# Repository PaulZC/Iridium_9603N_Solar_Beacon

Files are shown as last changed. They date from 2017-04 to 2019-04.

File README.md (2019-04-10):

# Iridium 9603N Solar Beacon

A 48g solar powered Iridium 9603N + GNSS Beacon (Tracker)

Suitable for high altitude ballooning, asset tracking and many other remote monitoring applications.

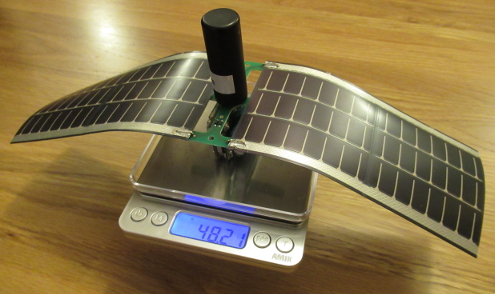
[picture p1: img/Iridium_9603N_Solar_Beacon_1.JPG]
Iridium_9603N_Solar_Beacon_1


The beacon can be powered by two [PowerFilm Solar MPT3.6-150 solar panels](https://www.powerfilmsolar.com/custom-solutions/electronic-component-solar-panels/electronic-component-solar-panels-product-page/mpt3-6-150).
It can also be powered via USB becoming an extremely small Iridium Beacon Base which you can use to track other beacons from anywhere.

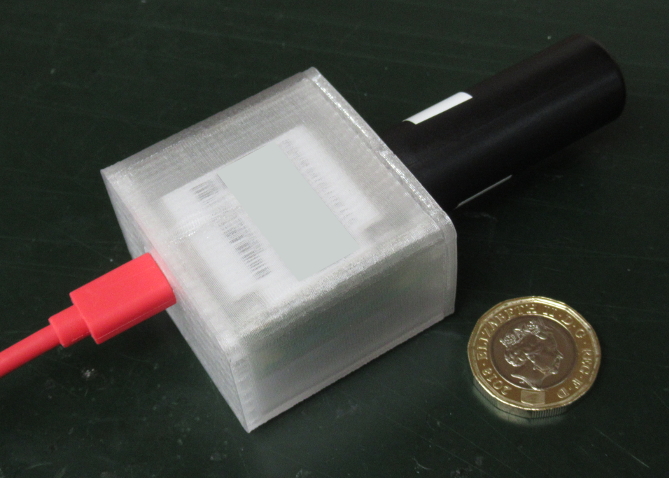
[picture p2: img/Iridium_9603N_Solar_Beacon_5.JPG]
Iridium_9603N_Solar_Beacon_5


The Iridium 9603N and u-blox MAX-M8Q GNSS share a single antenna. Antenna switching is performed by a Skyworks AS179-92LF RF Switch.

**See [LEARN.md](https://github.com/PaulZC/Iridium_9603N_Solar_Beacon/blob/master/LEARN.md) for more details.**

**See [ASSEMBLY.md](https://github.com/PaulZC/Iridium_9603N_Solar_Beacon/blob/master/ASSEMBLY.md) for details on how to assemble the PCB.**

See [Iridium_9603N_Solar_Beacon.pdf](https://github.com/PaulZC/Iridium_9603N_Solar_Beacon/blob/master/Iridium_9603N_Solar_Beacon.pdf) for the schematic, layout and Bill Of Materials.

The [Eagle](https://github.com/PaulZC/Iridium_9603N_Solar_Beacon/tree/master/Eagle) directory contains the schematic and pcb design files.

The [Arduino](https://github.com/PaulZC/Iridium_9603N_Solar_Beacon/tree/master/Arduino) directory contains the Arduino code.

The [OpenSCAD](https://github.com/PaulZC/Iridium_9603N_Solar_Beacon/tree/master/OpenSCAD) directory contains the .stl and .scad files for the 3D-printed cover and antenna spacer.

Please refer to the [Iridium_9603_Beacon Repo](https://github.com/PaulZC/Iridium_9603_Beacon/blob/master/RockBLOCK.md) for details on how to track your beacon
via the RockBLOCK Gateway with or without an Internet connection. If you are configuring the Solar Beacon as a Base, please make sure you use the version of
the Base code included in this Repo as the solar beacon pin definitions are slightly different and the code needs to ensure the 9603N and MAX-M8Q are not
powered up simultaneously when sharing the antenna.

If you have found this project useful and if you are able to, please cite the paper:

P. Clark et al, An open source toolkit for the tracking, termination and recovery of high altitude balloon flights and payloads, 2019 JINST 14 P04003
[DOI:10.1088/1748-0221/14/04/P04003](https://doi.org/10.1088/1748-0221/14/04/P04003)

The Accepted Manuscript is available on arXiv: http://arxiv.org/abs/1904.04321

This project is distributed under a Creative Commons Attribution + Share-alike (BY-SA) licence.
Please refer to section 5 of the licence for the "Disclaimer of Warranties and Limitation of Liability".

Enjoy!

**_Paul_**

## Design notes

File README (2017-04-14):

########################################
# Iridium 9603N Solar Beacon Prototype #
########################################

A breadboard prototype for a Solar Powered Iridium 9603N Beacon.

Power for the beacon is provided by a PowerFilm MPT3.6-150 solar panel.

Power for the Iridium 9603N is provided by a Linear Technology LTC3225EDDB supercapacitor charger.

See Iridium_9603N_Solar_Beacon_Prototype.pdf for a full description of the project:
https://github.com/PaulZC/Iridium_9603N_Solar_Beacon/blob/master/Iridium_9603N_Solar_Beacon_Prototype.pdf

The Arduino code can be found in Iridium9603NSolarBeaconPrototype
https://github.com/PaulZC/Iridium_9603N_Solar_Beacon/tree/master/Iridium9603NSolarBeaconPrototype

A Fritzing hook-up diagram can be found in Iridium_9603N_Solar_Beacon_Prototype_Fritzing.png
https://github.com/PaulZC/Iridium_9603N_Solar_Beacon/blob/master/Iridium_9603N_Solar_Beacon_Prototype_Fritzing.png

This project is distributed under a Creative Commons Attribution + Share-alike (BY-SA) licence.

Enjoy!

Paul

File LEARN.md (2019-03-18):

# Iridium 9603N Solar Beacon

A 48g solar powered Iridium 9603N + GNSS Beacon (Tracker)

Suitable for high altitude ballooning, asset tracking and many other remote monitoring applications.

Iridium_9603N_Solar_Beacon_1

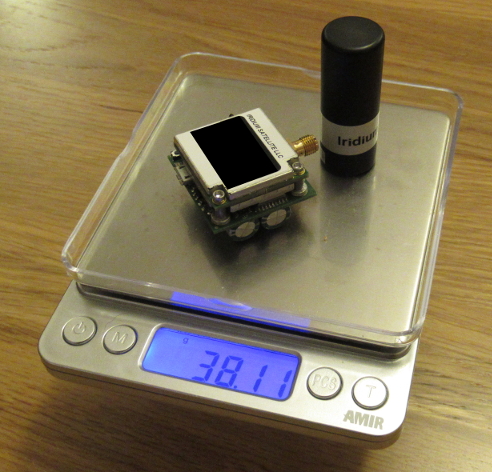
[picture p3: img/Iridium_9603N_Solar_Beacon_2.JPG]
Iridium_9603N_Solar_Beacon_2


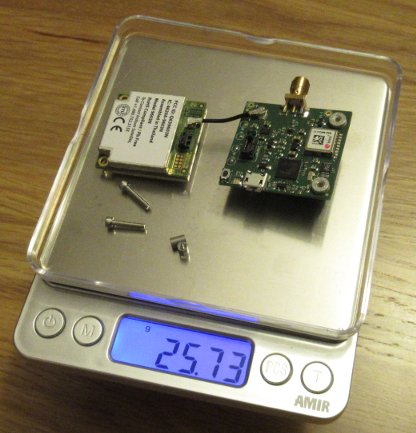
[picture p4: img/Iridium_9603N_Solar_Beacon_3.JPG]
Iridium_9603N_Solar_Beacon_3


## Background

The Iridium 9603N Solar Beacon is a miniature version of the [Iridium_9603_Beacon](https://github.com/PaulZC/Iridium_9603_Beacon).
It can be powered by two [PowerFilm Solar MPT3.6-150 solar panels](https://www.powerfilmsolar.com/custom-solutions/electronic-component-solar-panels/electronic-component-solar-panels-product-page/mpt3-6-150)
but can also be powered via USB becoming an extremely small Iridium Beacon Base which you can use to track other beacons without an Internet connection.

Iridium_9603N_Solar_Beacon_5

## The Design

See [Iridium_9603N_Solar_Beacon.pdf](https://github.com/PaulZC/Iridium_9603N_Solar_Beacon/blob/master/Iridium_9603N_Solar_Beacon.pdf) for the schematic,
layout and Bill Of Materials.

The [Eagle](https://github.com/PaulZC/Iridium_9603N_Solar_Beacon/tree/master/Eagle) directory contains the schematic and pcb design files.

The key components of the Iridium 9603N Solar Beacon are:

### Iridium 9603N Module
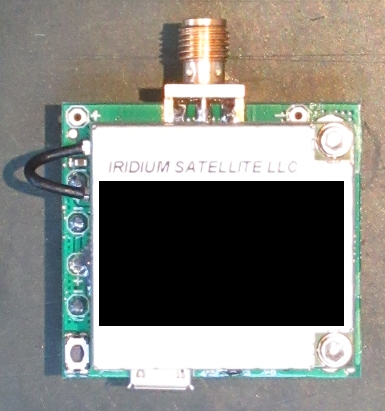
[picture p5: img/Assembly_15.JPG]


Available from:
- https://www.rock7.com/shop-product-detail?productId=50

Other UK and International distributors can be found at:
- https://www.iridium.com/where-to-buy/?pid=27083

Make sure you purchase the 9603N and not the older 9603. The 9603N will run from 5V ± 0.5V which is important as the super capacitor charger is set to produce 5.3V; the older 9603 is only rated to 5V ± 0.2V.

### SMA Iridium + GNSS Antenna
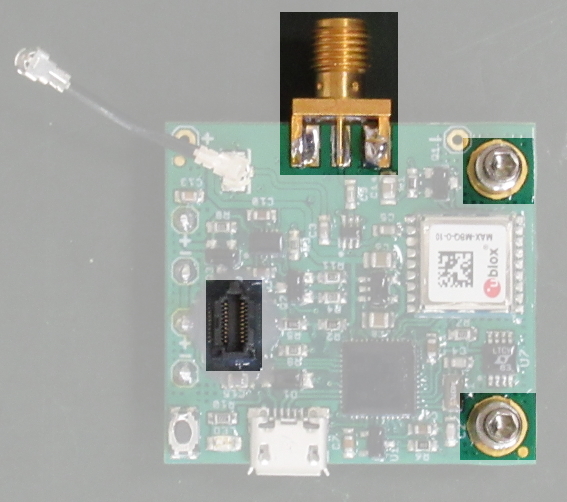
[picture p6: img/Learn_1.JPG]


For this version of the beacon, I recommend using the Maxtena M1600HCT-P-SMA which is tuned for the Iridium, GPS and GLONASS frequency bands.

### Atmel ATSAMD21G18 Processor
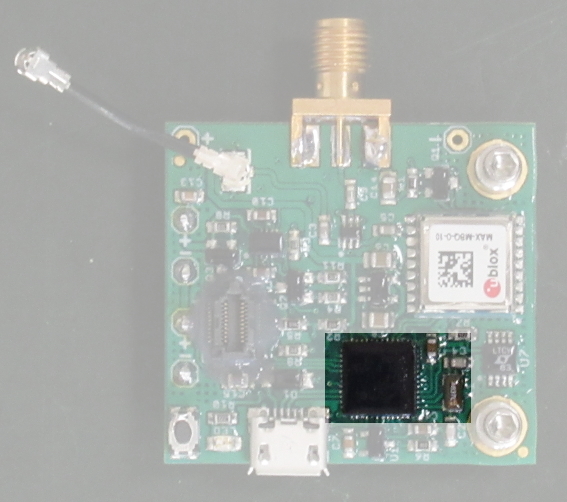
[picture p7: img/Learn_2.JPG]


As used on the Adafruit Feather M0:
- https://www.adafruit.com/products/2772

Available from e.g. Farnell / Element14 (2460544)

### Linear Technology LTC3225EDDB SuperCapacitor Charger
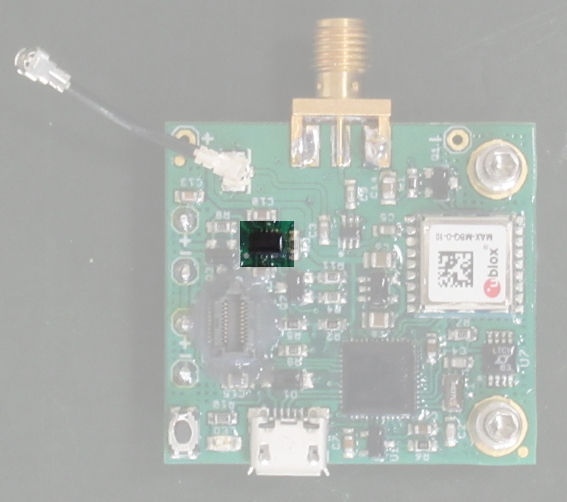
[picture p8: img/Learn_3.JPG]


- https://www.analog.com/en/products/ltc3225.html

Available as a bare chip from e.g. Farnell / Element14 (1715231)

### u-blox MAX-M8Q GNSS
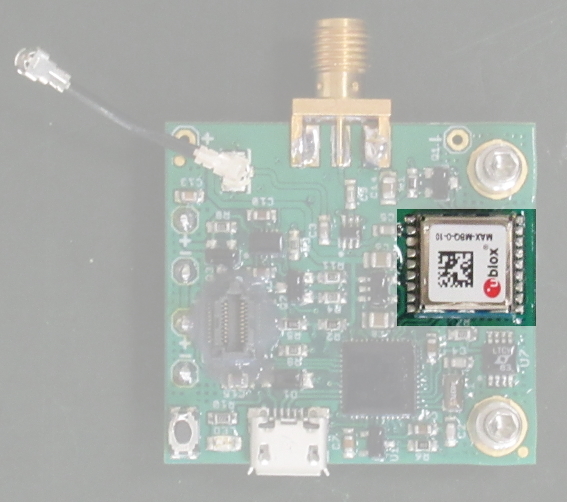
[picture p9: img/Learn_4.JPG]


- https://www.u-blox.com/en/product/max-m8-series

### MCP111T-240 Reset Supervisor
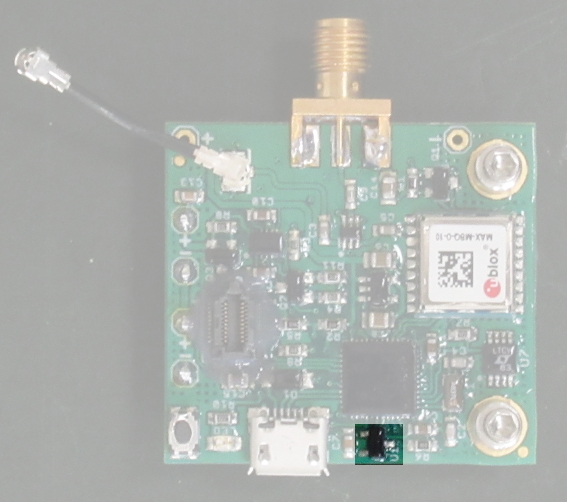
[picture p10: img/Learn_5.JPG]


The SAMD21G18 has a built-in power-on reset and brown-out detector circuit, but it doesn't work properly if the supply voltage rises very slowly.
The SAMD21G18 datasheet isn’t much help here. Section 8.2.4.1 specifies:
- _Minimum Rise Rate_

   _The integrated power-on reset (POR) circuitry monitoring the VDDANA power supply requires a minimum rise rate._

But then the supply characteristics section (37.4) specifies a _maximum_ supply rise rate of 0.1V/µs, not a minimum.

Tests I've carried out show that the processor will reset correctly if the power supply ramps up at 0.3 V/s or more, but fails to reset correctly at 0.2 V/s or less.
As the solar panel voltage will ramp up very slowly at sunrise, I've included a separate reset supervisor.
The Microchip MCP111-240 has an open drain output which holds the processor in reset until the supply rises above 2.4V, ensuring a clean start.

### SPX3819-3.3 Voltage Regulator
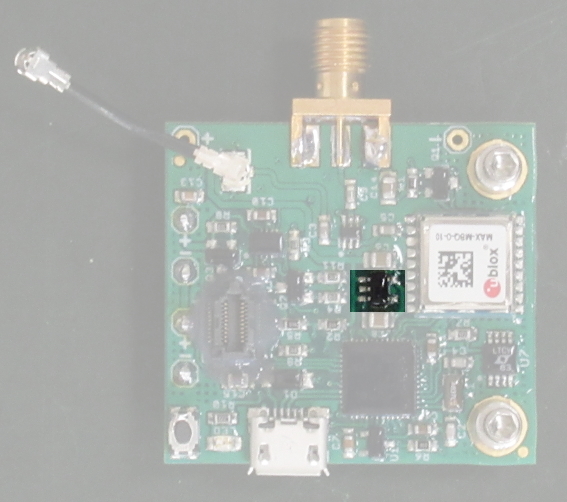
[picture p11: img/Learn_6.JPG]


The SPX3819-3.3 Voltage Regulator regulates the output from the two solar panels, or the USB port, providing 3.3V for the processor and GNSS.

The LTC3225EDDB SuperCapacitor Charger draws its power directly from the solar panels or USB without going through the regulator.

MBR120 diodes protect the solar panels and the USB port from each other.

### LT1634BCMS8-1.25 1.25V Voltage Reference
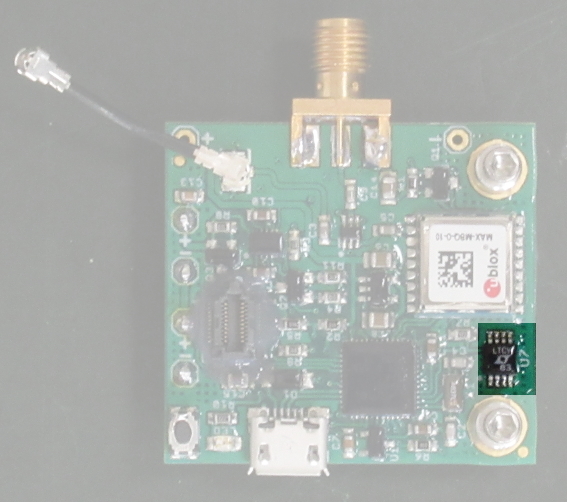
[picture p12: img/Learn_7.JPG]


The SAMD21G18 processor is powered from a low drop-out 3.3V regulator. The solar / USB voltage is measured via an analog pin connected to the mid point
of two 100K resistors configured as a voltage divider. The voltage measured by the analog pin is relative to the regulator voltage. When the power voltage drops below approximately
3.7V, the regulator voltage starts to collapse. The analog voltage appears to never drop below approximately 3.4V even when the actual voltage is lower than this.

By adding a 1.25V voltage reference and connecting it to a second analog pin, its constant voltage will appear to increase as the regulator voltage starts to collapse.
This voltage increase can be used to correct the power voltage measurement.

### Skyworks AS179-92LF RF Switch

The Iridium 9603N and MAX-M8Q GNSS receiver share the same antenna. A Skyworks AS179-92LF RF switch is used to switch the antenna connection from one to the other according to which is powered up.
Most importantly, the RF switch disconnects and protects the GNSS receiver when the Iridium 9603N is transmitting.

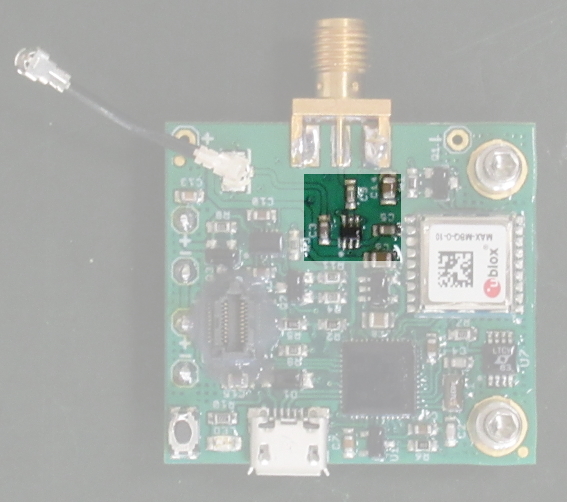
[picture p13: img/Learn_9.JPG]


Switching is performed by applying either EXT_PWR or 3V3SW to the AS179's V1 and V2 pins.
EXT_PWR is the 5.3V power rail for the 9603N (switched via Q2 and Q3, enabled by pulling MISO/D22 high).
3V3SW is the 3.3V power rail for the MAX-M8Q (switched via Q1, enabled by pulling D11 low).
When modifying the Arduino code, take great care to make sure EXT_PWR and 3V3SW are not enabled at the same time.
**BADS THINGS WILL PROBABLY HAPPEN IF YOU DO ENABLE BOTH SIMULTANEOUSLY!**

### Two PowerFilm Solar MPT3.6-150 solar panels


- https://www.powerfilmsolar.com/custom-solutions/electronic-component-solar-panels/electronic-component-solar-panels-product-page/mpt3-6-150

Available (in the UK) from e.g.:
- http://www.selectsolar.co.uk/prod/264/powerfilm-mpt36150-100ma-36v-mini-solar-panel

### Iridum 9603N Power Switching

The datasheet for the 9603N contains a note which says:

_When a transceiver has been turned off, Product Developers should not reapply power on a unit until more than 2 seconds has elapsed after power has reached 0V. Additionally, if a unit does not respond to AT commands, power off the module, wait for 2 seconds and then power it back on._

_When a 9603 is powered off the power on reset circuit requires 2 seconds for voltages to decay. If the 2 second wait time is not adhered to the reset circuit may not operate and the modem could be placed in a non-operational state. The state is not permanent and can be rectified by the above procedure._

I have seen a 9603N go into this non-operational state only twice. Unfortunately, with the previous versions of the beacon design,
the only way to completely remove power to the 9603N was to manually discharge the super capacitors. Obviously it would be disastrous if this happened
during a flight. So, a P-MOSFET (Q3) is used as a switch to disconnect the power to the 9603N when required.

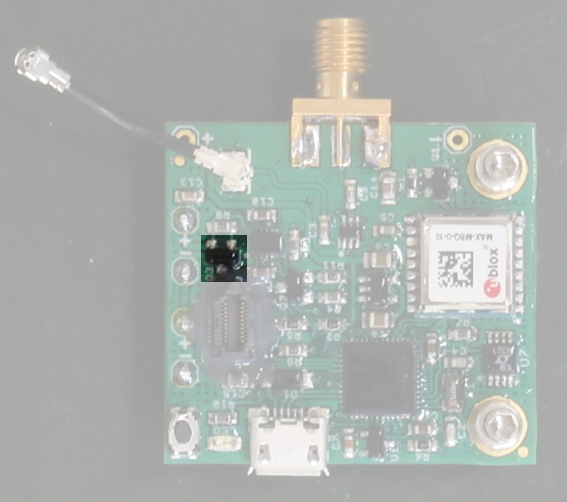
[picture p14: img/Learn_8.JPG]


### IO Pins
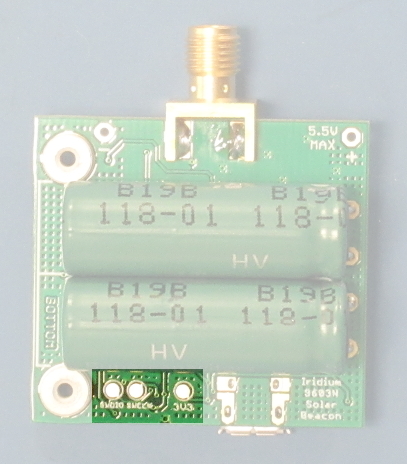
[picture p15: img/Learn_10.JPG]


**SWCLK** and **SWDIO** are used during [programming of the SAMD bootloader](https://github.com/PaulZC/Iridium_9603N_Solar_Beacon/blob/master/LEARN.md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)

**3V3** is the 3.3V power rail from the SPX3819-3.3 voltage regulator.

## Why does the beacon LED flash?
The small red LED indicates what the beacon software is doing. The LED:

- will flash at 0.5Hz (1 second on, 1 second off) while the u-blox GNSS is establishing a fix
- will flash at 1Hz (0.5 seconds on, 0.5 seconds off) while the supercapacitors are charging
- will flash at 1.5Hz (0.333 seconds on, 0.333 seconds off) during the Iridium Short Burst Data exchange
- will flash rapidly (5Hz) ten times if the SBD exchange was successful
- goes out when the beacon is in deep sleep
- will fade up and down when the SAMD processor is in bootloader mode (the same as the Arduino Zero)

## Why do you need the Super Capacitors?
The Iridium 9603 module draws an average current of 145mA and a peak current of 1.3A when transmitting its short data bursts. That's too much for the solar panels to provide.
The LTC3225 super capacitor charger draws a lower current from the panels to slowly charge two 2.7V capacitors, connected in series, to 5.3V. The capacitors then deliver the 1.3A to the module when it sends the data burst.

## Why is the Super Capacitor Charger charge current set to 60mA?
The datasheet for the 9603N quotes: an average idle current of 34mA; and an average receive current of 39mA.

For solar operation, we need to charge the capacitors at a higher current than 39mA, but keep the total current draw within what the solar panels can deliver.
(The LTC3225 has an efficiency of approximately 50% and hence draws approximately _twice_ the chosen charge current.)
The 10F capacitors provide the majority of the higher current draw during the transmit cycle.

For USB operation the super capacitor charge current can be set to 150mA and smaller (1F) super capacitors are adequate.

## Can I leave the USB connected during testing?
Yes. Leaving the USB connected is useful as you can monitor the Serial messages produced by the code in the Arduino IDE Serial Monitor.
If you use a standard USB cable then the beacon will draw power from USB. To test the beacon running on solar power, you will need to break the USB 5V power connection.
You can do this with a home-made power-break cable.

Take a short male to female USB extension cable; carefully strip the outer sheath from cable somewhere near the middle;
prise apart the screen connection to reveal the four USB wires (red (5V); black (GND); green and white (data)); cut and insulate the ends of the red 5V wire leaving the black, green and white wires and the screen connection intact:

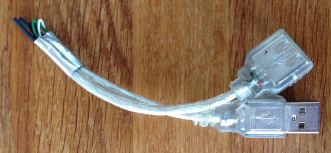
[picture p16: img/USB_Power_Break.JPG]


## Arduino Code
The [Arduino](https://github.com/PaulZC/Iridium_9603N_Solar_Beacon/tree/master/Arduino) directory contains the Arduino code.

The code is based extensively on Mikal Hart’s IridiumSBD Beacon example:
- https://github.com/mikalhart/IridiumSBD/tree/master/examples/Beacon

The main loop is structured around a large switch / case statement which:
- Initialises the serial ports; checks the solar panel voltage
- Powers up the GPS; checks the solar panel voltage
- Waits until the GPS establishes a fix; checks the solar panel voltage
- Powers down the GPS and powers up the LTC3225EDDB supercapacitor charger; checks the solar panel voltage
- Waits for the supercapacitors to charge; checks the solar panel voltage
- Queues the Iridium message transmission; checks the solar panel voltage
- Powers everything down and puts the processor to sleep until the next alarm interrupt

If the solar panel voltage falls below a useful level at any time, the code jumps to the sleep case and waits for the next alarm interrupt.

The BEACON_INTERVAL is stored in non-volatile (flash) memory internal to the SAMD21 processor and can be updated via a Mobile Terminated (MT) SBD message.

## How do I install the ATSAMD21G18 bootloader?
Get yourself a Segger J-Link programmer and connect it according to [Atmel_SAMD21_Programming_Cable.pdf](https://github.com/PaulZC/Iridium_9603N_Solar_Beacon/blob/master/Atmel_SAMD21_Programming_Cable.pdf).

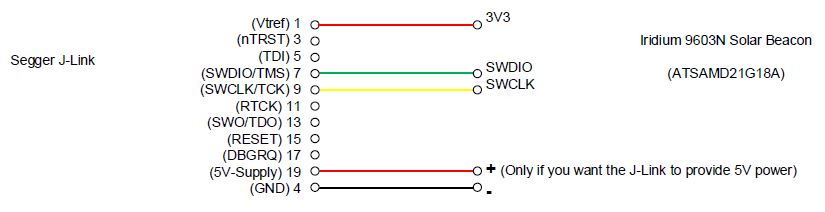
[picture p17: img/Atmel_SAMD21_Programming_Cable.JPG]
Atmel_SAMD21_Programming_Cable


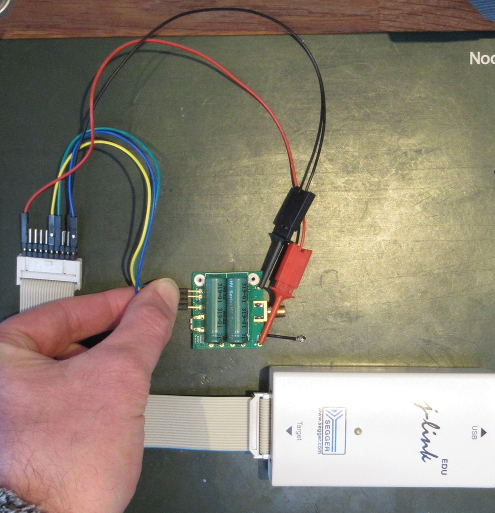
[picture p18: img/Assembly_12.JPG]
Assembly_12


Connect the 5V-Supply output from the J-Link to the + pad to power the board while you configure it (it doesn’t need external power for this bit).

Follow Lady Ada’s excellent instructions:
- https://learn.adafruit.com/proper-step-debugging-atsamd21-arduino-zero-m0/restoring-bootloader

If you are using Atmel's Studio:

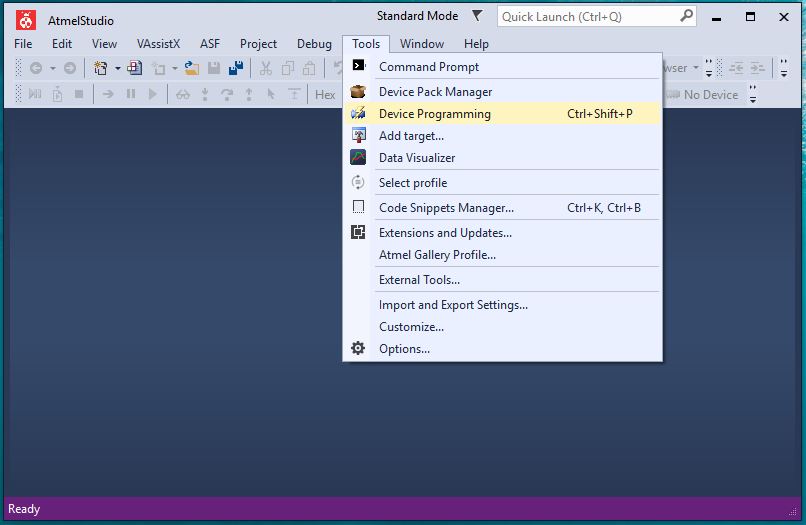
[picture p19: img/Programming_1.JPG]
Programming_1


Select Tools \ Device Programming

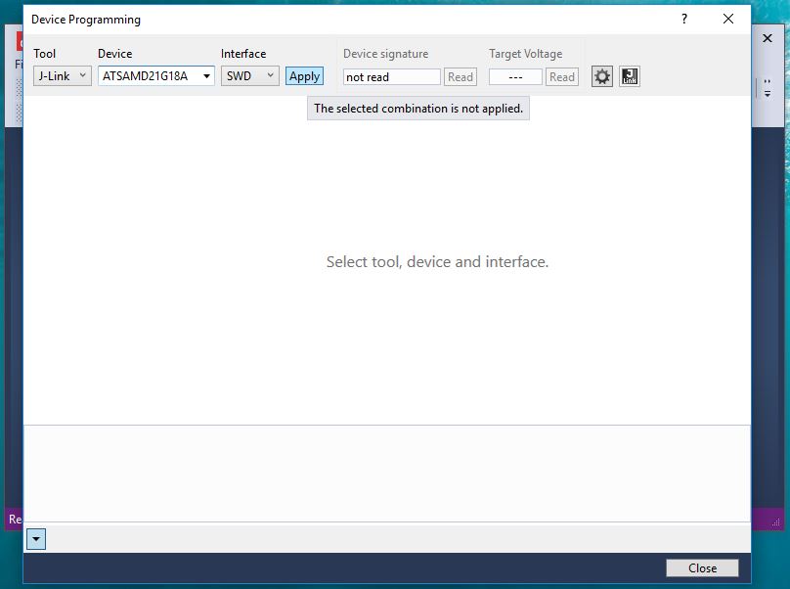
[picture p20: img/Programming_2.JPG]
Programming_2


Select J-Link in the Tool pull-down menu
Select ATSAMD21G18A in the Device pull-down menu
Select SWD in the Interface pull-down menu
Then click Apply

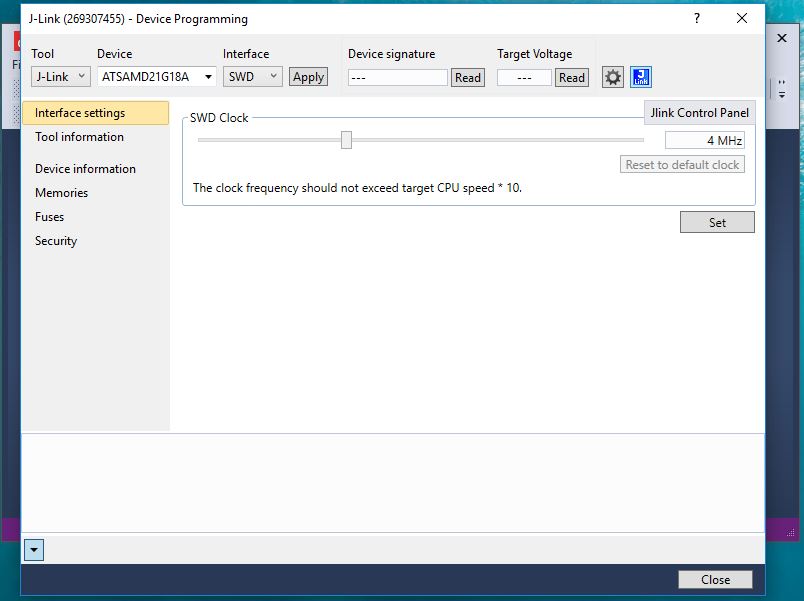
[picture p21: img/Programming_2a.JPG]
Programming_2a


Click the J-Link icon to apply target power to the beacon

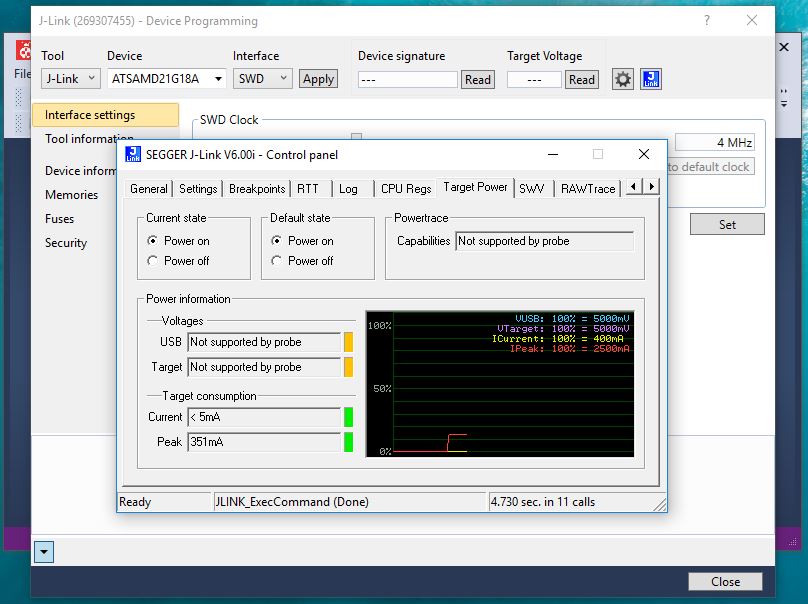
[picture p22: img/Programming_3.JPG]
Programming_3


Select the Target Power tab and set Current State to Power On. This will apply 5V power from the J-Link
to the beacon VBUS

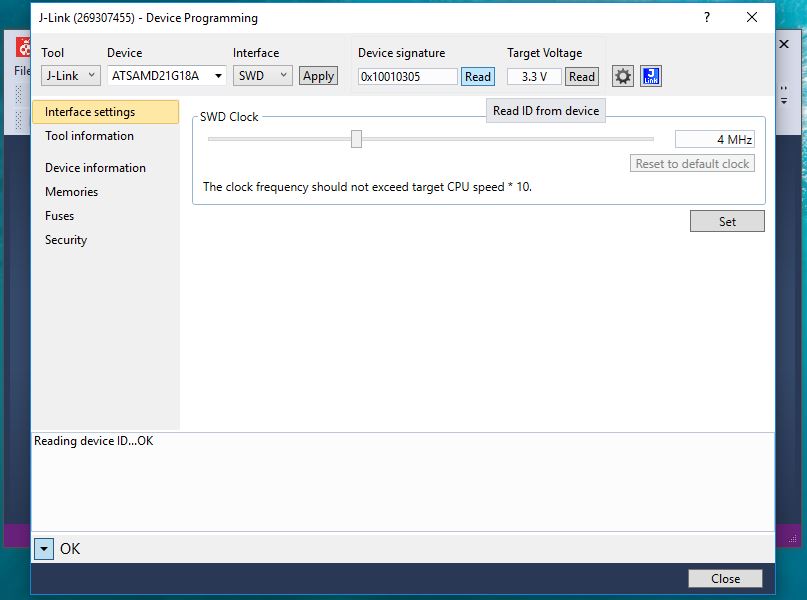
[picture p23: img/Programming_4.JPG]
Programming_4


Close the J-Link window. In the Device Programming window click 'Read' to read the Device Signature and Target Voltage

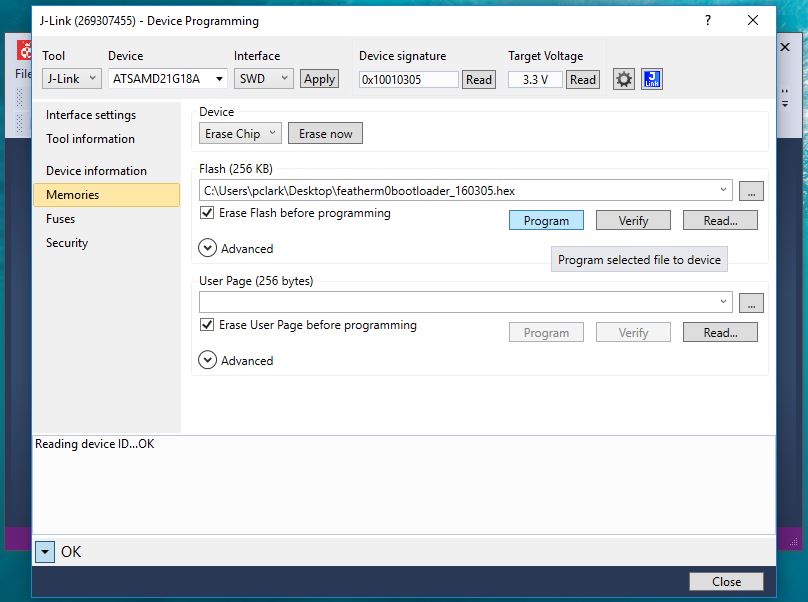
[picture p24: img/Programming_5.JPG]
Programming_5


Click 'Memories', click the '...' icon to select the bootloader Flash file
Click Program to erase, program and verify the device

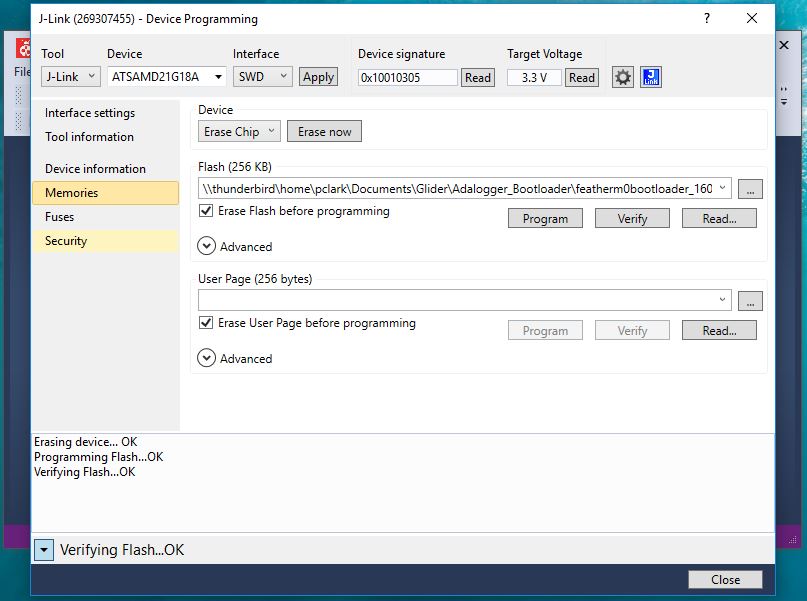
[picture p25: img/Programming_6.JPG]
Programming_6


Finally, select the J-Link icon again, select the Target Power tab and set Current State to Power Off
Close Device Programming and Atmel Studio and you are ready to configure the Beacon with the Arduino code

## How do I upload the Arduino code?
The 9603 Beacon is based on the Adafruit Feather M0 (Adalogger):
- https://www.adafruit.com/products/2796
- https://www.adafruit.com/products/2772

You can follow Lady Ada’s excellent instructions:
- https://cdn-learn.adafruit.com/downloads/pdf/adafruit-feather-m0-adalogger.pdf

## What other libraries do I need?
The main one is Mikal Hart’s Iridium SBD library (V2.0) written for the Rock7 RockBLOCK:
- http://arduiniana.org/libraries/iridiumsbd/
- https://github.com/mikalhart/IridiumSBD

The code uses Cristian Maglie's FlashStorage library to store and retrieve the BEACON_INTERVAL setting:
- https://github.com/cmaglie/FlashStorage

You will also need:
- https://github.com/mikalhart/TinyGPS
- http://arduiniana.org/libraries/pstring/
- https://github.com/arduino-libraries/RTCZero

## What data will I get back from the beacon?

The Arduino code included in this repository will send the following (separated by commas):
- GPS Time and Date (year, month, day, hour, minute, second)
- GPS Latitude (degrees)
- GPS Longitude (degrees)
- GPS Altitude (m)
- GPS Speed (m/s)
- GPS Heading (degrees)
- GPS HDOP (m)
- GPS Satellites
- Solar voltage (V)
- Iteration count

E.g.:

   _20170729144631,55.866573,-2.428458,103,0.1,0,3.0,5,0,0.0,4.98,0_

You can opt to receive the data as an email attachment from the Iridium system. The email itself contains extra useful information:
- Message sequence numbers (so you can identify if any messages have been missed)
- The time and date the message session was processed by the Iridium system
- The status of the message session (was it successful or was the data corrupt)
- The size of the message in bytes
- The approximate latitude and longitude the message was sent from
- The approximate error radius of the transmitter’s location

E.g.:

   _From:	sbdservice@sbd.iridium.com_  
   _Sent:	20 August 2016 16:25_  
   _To:_  
   _Subject:	SBD Msg From Unit: 30043406174_  
   _Attachments:	30043406174-000029.sbd_  
  
   _MOMSN: 29_  
   _MTMSN: 0_  
   _Time of Session (UTC): Sat Aug 20 15:24:57 2016 Session Status: 00 - Transfer OK Message Size (bytes): 61_  
  
   _Unit Location: Lat = 55.87465 Long = -2.37135 CEPradius = 4_

You can adapt the code to send whatever data you like, up to a maximum of 340 bytes. The message is sent as plain text, but you could encrypt it if required.

You can opt to receive the data via HTTP instead of email. Your service provider will provide further details.

## Does the Solar Beacon work in exactly the same way as the Iridium 9603 Beacon?

Yes, with the exception that the solar beacon does not have an MPL3115A2 pressure and temperature sensor. The messages produced by the solar beacon have the same
format as messages from its big brother; the pressure and temperature data is simply set to zero.

You can track the solar beacon from another solar beacon acting as a Base in exactly the same way as you can with the Iridium Beacon. Please refer to the
main [Iridium_9603_Beacon Repo](https://github.com/PaulZC/Iridium_9603_Beacon/blob/master/RockBLOCK.md) for full details. Please make sure you use the version of
the Base code included in this Repo as the solar beacon pin definitions are slightly different and the code needs to ensure the 9603N and MAX-M8Q are not
powered up simultaneously when sharing the antenna.

## Acknowledgements

This project wouldn’t have been possible without the open source designs and code kindly provided by:
- Adafruit:

   The Adafruit SAMD Board library  
   The design for the Feather M0 Adalogger  
   For more details, check out the product page at:
   - https://www.adafruit.com/product/2772  

   Adafruit invests time and resources providing this open source design, please support Adafruit and open-source hardware by purchasing products from Adafruit!  
   Designed by Adafruit Industries.  
   Creative Commons Attribution, Share-Alike license

   Sercom examples:
   - https://learn.adafruit.com/using-atsamd21-sercom-to-add-more-spi-i2c-serial-ports/creating-a-new-serial

- Mikal Hart:

   The Iridium SBD library (distributed under the terms of the GNU LGPL license)  
   TinyGPS  
   PString

- Arduino:

   The Arduino IDE  
   Arduino SAMD Board library  
   RTCZero library

- Cave Moa:

   The SimpleSleepUSB example:
   - https://github.com/cavemoa/Feather-M0-Adalogger/tree/master/SimpleSleepUSB

- MartinL:

   Sercom examples:
   - https://forum.arduino.cc/index.php?topic=341054.msg2443086#msg2443086

- Cristian Maglie:

   FlashStorage library:
   - https://github.com/cmaglie/FlashStorage

## Licence

This project is distributed under a Creative Commons Share-alike 4.0 licence.
Please refer to section 5 of the licence for the "Disclaimer of Warranties and Limitation of Liability".

Enjoy!

**_Paul_**

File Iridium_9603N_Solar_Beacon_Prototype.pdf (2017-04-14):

Iridium 9603N Solar Beacon Prototype Background:
Following on from the work I did on the Iridium_9603_Beacon: https://github.com/PaulZC/Iridium_9603_Beacon
which got some nice coverage on Hackaday: http://hackaday.com/2016/12/19/a-beacon-suitable-for-tracking-santas-sleigh/
and which flew on UBSEDS22 and sent updates all the way from the UK to China before the batteries gave up:
https://github.com/PaulZC/Iridium_9603_Beacon/blob/master/Iridium_9603_Beaco n.pdf (https://github.com/PaulZC/Iridium_9603_Beacon/blob/master/Iridium_9603_Beacon.pdf)
https://github.com/PaulZC/Iridium_9603_Beacon/blob/master/UBSEDS22I_KML/iridium_linestring.kml (https://github.com/PaulZC/Iridium_9603_Beacon/blob/master/UBSEDS22I_KML/iridium_linestring.kml)
I decided to set myself the challenge of modifying the design of the beacon to make it solar-powered, removing the need for the lithium batteries and allowing the beacon to send updates during daylight hours for as long as the balloon continues to float. The design I’ve ended up with is based largely on the prototype for the Iridium 9603 beacon https://github.com/PaulZC/Iridium_9603_Beacon_Prototype but is powered by a single PowerFilm Solar MPT3.6-150 solar panel: http://www.powerfilmsolar.com/products/?mpt36150&show=product&productID=271537&productCategoryIDs=6573 (http://www.powerfilmsolar.com/products/?mpt36150&show=product&productID=271537&productCategoryIDs=6573)
This amazing little panel weighs only 3.1g but can deliver a really useful amount of power: 100mA at 3.6V at Air Mass 1.5. This is enough to power the beacon’s SAMD21G18 processor and the GPS receiver or the LTC3225EDDB super capacitor charger which delivers power to the Iridium 9603N.
The current status is that the prototype has worked successfully under full sun at sea level in the UK (during April). The next step will be to condense the design onto a single PCB and ask those nice students at Bristol University UBSEDS if they might be able to fly it on another of their small super-pressure balloons.
Tell me about the design
The key components of the Iridium 9603N Solar Beacon Prototype are:

- Iridium 9603N Module
- Available (in the UK) from e.g.:
- http://www.ast-systems.co.uk/Product-Pages/Iridium-9603-SBD— Satellite-Tracking-Transceiver.aspx (http://www.ast-systems.co.uk/Product-Pages/Iridium-9603-SBD--Satellite-Tracking-Transceiver.aspx)
- http://www.rock7mobile.com/products-iridium-sbd
- Other UK and International distributors can be found at:
- https://iridium.com/products/details/Iridium-9603?section=wtb
- For breadboard prototyping, you can mount the module on a Satelligent 9603-DIP: http://satelligent.ca/products/accessories/9603-dip/
- Make sure you purchase the 9603N and not the older 9603 (the 9603N will run from 5V ± 0.5V which is important as the super capacitor charger will be set to produce 5.3V; the older 9603 is only rated to 5V ± 0.2V)
- Taoglas IP.1621.25.4.A.021 Iridium Patch Antenna
- Available from e.g. Mouser (Part# 960-IP1621254A02)
- You can mount this on a small PCB above the 9603N:
- https://github.com/PaulZC/Iridium_9603_Beacon/blob/master/Eagle/V2/Iridium_9603_Antenna.brd (https://github.com/PaulZC/Iridium_9603_Beacon/blob/master/Eagle/V2/Iridium_9603_Antenna.brd)
- And connect it to the 9603N with a short Molex uFL cable (part number 73412-0508, available from Farnell / Element14 (1340201))
- Linear Technology LTC3225EDDB SuperCapacitor Charger
- http://www.linear.com/product/LTC3225
- For breadboard prototyping, you can use Linear’s demo circuit (1220B):
- http://www.linear.com/solutions/2187
- Charges two e.g. Bussmann HV1030-2R7106-R 10F 2.7V capacitors (Farnell / Element14 2148486)
- Adafruit Feather M0 Adalogger
- https://www.adafruit.com/product/2796
- Adafruit Ultimate GPS Breakout
- https://www.adafruit.com/product/746
- SparkFun MPL3115A2 Altitude/Pressure Sensor Breakout
- https://www.sparkfun.com/products/11084
- PowerFilm Solar MPT3.6-150 solar panel
- http://www.powerfilmsolar.com/products/?mpt36150&show=product&productID=271537&productCategoryIDs=6573 (http://www.powerfilmsolar.com/products/?mpt36150&show=product&productID=271537&productCategoryIDs=6573)
- Available (in the UK) from e.g.:
- http://www.selectsolar.co.uk/prod/264/powerfilm-mpt36150-100ma-36v-mini-solar-panel (http://www.selectsolar.co.uk/prod/264/powerfilm-mpt36150-100ma-36v-mini-solar-panel)

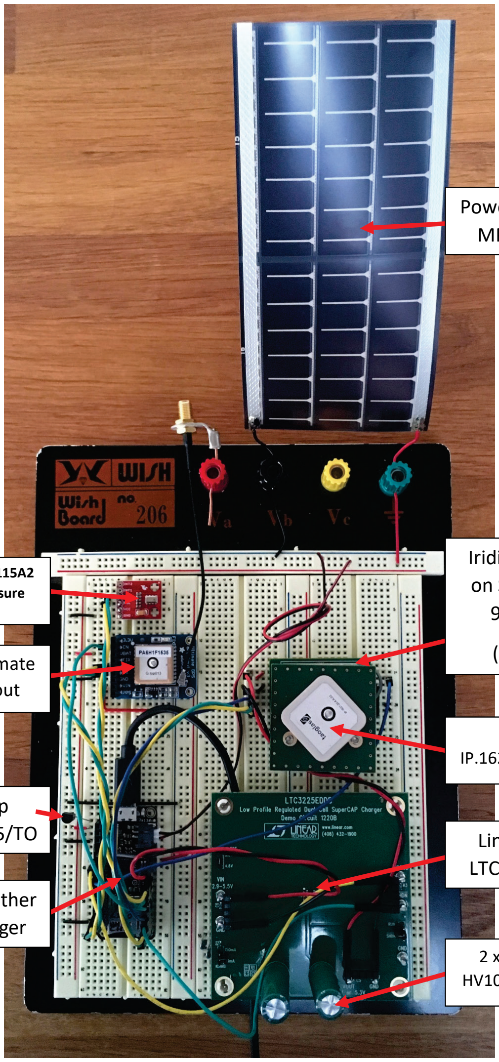
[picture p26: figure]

Microchip
MCP111-195/TO

SparkFun MPL3115A2
Altitude / Pressure
Sensor

Adafruit Ultimate
GPS Breakout

Adafruit Feather
M0 Adalogger

Linear Tech.
LTC3225EDDB

2 x Bussmann
HV1030-2R7106-R

Taoglas
IP.1621.25.4.A.021

Iridium 9603N
on Satelligent
9603-DIP
(Hidden)

PowerFilm Solar
MPT3.6-150

How do I connect everything? Here’s a Fritzing diagram to help:


Connect:
MPT3.6-150 Solar Panel V+ | to | Adalogger BAT / VBAT (or JST LiPo V+)
MPT3.6-150 Solar Panel V- | to | Adalogger GND (or JST LiPo V-)
MCP111-195/TO VDD | to | Adalogger 3V / 3V3 (Out)
MCP111-195/TO VSS | to | Adalogger GND
MCP111-195/TO VOUT | to | Adalogger RST
Ultimate GPS 3.3V (Out) | to | Sparkfun MPL3115A2 VCC
Ultimate GPS EN | to | Adalogger D11
Ultimate GPS VBAT (In) | to | Adalogger 3V / 3V3 (Out)
Ultimate GPS Tx (Out) | to | Adalogger RxD / D0 (In)
Ultimate GPS Rx (In) | to | Adalogger TxD / D1 (Out)
Ultimate GPS GND | to | Adalogger GND
Ultimate GPS VIN (In) | to | Adalogger USB / VBUS (Out)
Sparkfun MPL3115A2 SDA | to | Adalogger SDA / D20
Sparkfun MPL3115A2 SCL | to | Adalogger SCL / D21
Sparkfun MPL3115A2 GND | to | Adalogger GND
Iridium 9603N Pin 1 (EXT_PWR) (In) to | LTC3225EDDB VOUT
Iridium 9603N Pin 2 (EXT_PWR) (In) to | LTC3225EDDB VOUT
Iridium 9603N Pin 3 (EXT_GND) (In) to | LTC3225EDDB GND
Iridium 9603N Pin 4 (EXT_GND) (In) to | LTC3225EDDB GND
Iridium 9603N Pin 5 (ON/OFF) (In) | to | Adalogger D6
Iridium 9603N Pin 6 (DF_S_TX) (In) to | Adalogger D10
Iridium 9603N Pin 7 (DF_S_RX) (Out) to | Adalogger D12
Iridium 9603N Pin 13 (DF_RTS) (In) to | Iridium 9603N Pin 18 (SIG_GND)
Iridium 9603N Pin 14 (DF_DTR) (In) to | Iridium 9603N Pin 15 (SIG_GND)
Iridium 9603N Pin 19 (Net Avail) (Out)to | Adalogger A3 / D17
LTC3225EDDB VIN | to | Adalogger USB / VBUS (Out)
LTC3225EDDB GND | to | Adalogger GND
LTC3225EDDB PGOOD | to | Adalogger A1 / D15
LTC3225EDDB SHDN | to | Adalogger D5

Tell me about the Arduino code
You can find the Arduino code for the Adalogger in: https://github.com/PaulZC/Iridium_9603N_Solar_Beacon/tree/master/Iridium9603N SolarBeaconPrototype (https://github.com/PaulZC/Iridium_9603N_Solar_Beacon/tree/master/Iridium9603NSolarBeaconPrototype)

The code is based extensively on Mikal Hart’s IridiumSBD Beacon example: https://github.com/mikalhart/IridiumSBD/tree/master/examples/Beacon The main loop is structured around a large switch / case statement which:
- Initialises the serial ports; checks the solar panel voltage
- Powers up the GPS and MPL3115A2; checks the solar panel voltage
- Waits until the GPS establishes a fix; checks the solar panel voltage
- Reads the temperature and pressure from the MPL3115A2
- Powers down the GPS and powers up the LTC3225EDDB supercapacitor charger; checks the solar panel voltage
- Waits for the supercapacitors to charge; checks the solar panel voltage
- Queues the Iridium message transmission; checks the solar panel voltage
- Powers everything down and puts the processor to sleep until the next alarm interrupt
If the solar panel voltage falls below a useful level at any time, the code jumps to the sleep case and waits for the next alarm interrupt.
What other libraries do I need?
The main one is Mikal Hart’s Iridium SBD library. It was written for the Rock7 RockBLOCK, which uses the Iridium 9602 module, but it works just fine on the 9603: http://arduiniana.org/libraries/iridiumsbd/
https://github.com/mikalhart/IridiumSBD
You will also need:
https://github.com/mikalhart/TinyGPShttp://arduiniana.org/libraries/pstring/https://github.com/adafruit/Adafruit_MPL3115A2_Libraryhttps://github.com/arduino-librarie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
Do I need the reset supervisor?
The SAMD21G18 has a built-in power-on reset and brown-out detector circuit, but the solar panel will ramp up its output voltage very slowly at sunrise so I would recommend including a separate reset supervisor. The Microchip MCP111-195 has an open drain output which can be used to reset the processor whenever the 3.3V supply falls below 1.95V.

The SAMD21G18 datasheet isn’t much help here. Section 8.2.4.1 specifies:
Minimum Rise Rate
The integrated power-on reset (POR) circuitry monitoring the VDDANA power supply requires a minimum rise rate.
But then the supply characteristics section (37.4) specifies a maximum supply rise rate of 0.1V/µs. The solar panel rise rate will be much slower than that.
Do I need to modify the Adalogger?
Yes. You’ll need to remove the LiPo charger chip, otherwise when you connect to the Adalogger via USB the LiPo charger will attempt to charge the solar panel which will almost certainly damage it. The easiest way to remove the LiPo charger is to carefully cut through the chip legs with a scalpel blade.


Where do I connect the solar panel?
If you have a convenient cable with a JST connector on the end, maybe a cable taken from an old LiPo cell, you can connect the solar panel directly to the Adalogger LiPo battery connector. If you don’t have a suitable cable, connect the panel V+ strip to the BAT pin and the V- strip to GND:


V-V+
V+

V-

We use the BAT connection as it includes an MBR120 diode which will protect the solar panel when the Adalogger is powered via USB:


Do I need to modify the LTC3225EDDB Demo Circuit?
Yes. You’ll need to remove the slim 0.25F capacitor from the back of the PCB and add two e.g. Bussmann HV1030-2R7106-R 10F 2.7V capacitors instead. You can also solder pin headers onto the terminals to make it easy to use hook-up wires and glue single pin headers into the legs so it will sit securely in breadboard.
Bizarrely, Linear decided to use a four layer board and provided no thermal relief on the C4 –ve pin. This makes it almost impossible to solder. I had to leave the capacitor leg long, bend it over and solder it to the –ve pad for the original slim capacitor.


Make sure that:


- The VOUT_SELECT jumper link is set to 5.3V
- The RUN/SHDN and ICHRG jumper links are removed
From this:

To this:


To set the charge current to 60mA:


- Solder two short lengths of solid core wire to two pins on the ICHG header
- Bend these wires down, cut and strip them to the correct length so they can poke into breadboard
- Add two 22K resistors in series to change the combined PROG resistance to 30K (60.4K in parallel with 15K + 22K + 22K)
- http://cds.linear.com/docs/en/demo-board-manual/dc1220B.pdf


Why 60mA?
The datasheet for the 9603N quotes: an average idle current of 34mA; and an average receive current of 39mA. We need to charge the capacitors at a higher current than this, but keep the total current draw within what the solar panel can deliver.

Why do you need the Super Capacitors?
The Iridium 9603 module draws an average current of 145mA and a peak current of 1.3A when transmitting its short data bursts. That’s too much for the solar panel to provide. The LTC3225 super capacitor charger draws 60mA from the panel to charge two 10F 2.7V capacitors, connected in series, to 5.3V. The capacitors then deliver the 1.3A to the module when it sends the data burst.
Will you modify the design for the PCB version?
Yes. The main changes will be:
- Replace the GlobalTop FGPMMOPA6H GPS receiver (used on the Adafruit Ultimate GPS Breakout) with the u-blox SAM-M8Q:
- https://www.u-blox.com/en/product/sam-m8q-module
- Add a second MPT3.6-150 solar panel with its own MBR120 diode

Can I leave the Adalogger USB connected during testing?
Yes. Leaving the USB connected is useful as you can monitor the Serial messages produced by the code in the Arduino IDE Serial Monitor. If you use a standard USB cable then the Adalogger will draw its power from USB. To test the prototype running on solar power, you will need to break the USB 5V power connection. You can do this with a home-made power-break cable. Take a short male to female USB extension cable; carefully strip the outer sheath from cable somewhere near the middle; prise apart the screen connection to reveal the four USB wires (red (5V); black (GND); green and white (data)); cut and insulate the ends of the red 5V wire leaving the black, green and white wires and the screen connection intact:


Thanks!
I’m very grateful to Richard Meadows and his fellow students at UBSEDS (University of Bristol Students for the Exploration and Development of Space). http://www.bristol-seds.co.uk/
I’m also very grateful to the UKHAS (UK High Altitude Society) team who provide the habhub flight tracker:
https://ukhas.org.uk/
http://tracker.habhub.org/
This project wouldn’t have been possible without the open source designs and code kindly provided by:
- Adafruit:
- the Adafruit SAMD Board library
- the design for the Feather M0 Adalogger
- For more details, check out the product page at
- https://www.adafruit.com/product/2772
- Adafruit invests time and resources providing this open source design, please support Adafruit and open-source hardware by purchasing products from Adafruit!
- Designed by Adafruit Industries.
- Creative Commons Attribution, Share-Alike license
- the MPL3115A2 library
- sercom examples
- https://learn.adafruit.com/using-atsamd21-sercom-to-add-more-spi-i2c-serial-ports/creating-a-new-serial (https://learn.adafruit.com/using-atsamd21-sercom-to-add-more-spi-i2c-serial-ports/creating-a-new-serial)
- Mikal Hart:
- the Iridium SBD library (distributed under the terms of the GNU LGPL license)
- TinyGPS
- PString
- Sparkfun:
- the MPL3115A2 Breakout
- https://www.sparkfun.com/products/11084
- Arduino:
- the Arduino IDE

- Arduino SAMD Board library
- RTCZero library
- Cave Moa:
- the SimpleSleepUSB example
- https://github.com/cavemoa/Feather-M0-Adalogger/tree/master/SimpleSleepUSB (https://github.com/cavemoa/Feather-M0-Adalogger/tree/master/SimpleSleepUSB)
- MartinL:
- sercom examples
- https://forum.arduino.cc/index.php?topic=341054.msg244308 6#msg2443086 (https://forum.arduino.cc/index.php?topic=341054.msg2443086#msg2443086)
The small print
This project is distributed under a Creative Commons Share-alike 4.0 (http://creativecommons.org/licenses/by-sa/4.0/) licence.
Please refer to section 5 of the licence for the “Disclaimer of Warranties and Limitation of Liability”.

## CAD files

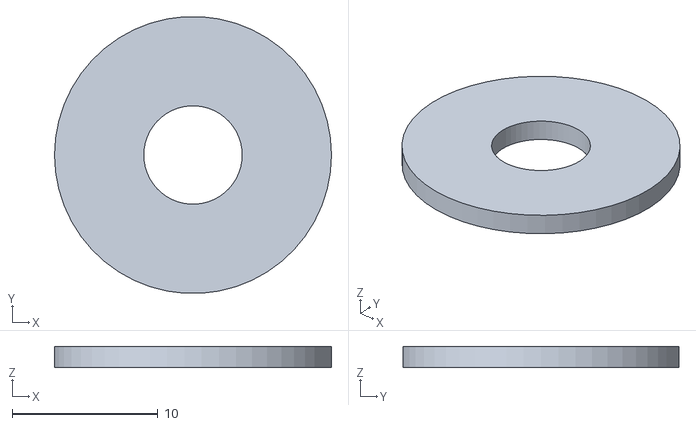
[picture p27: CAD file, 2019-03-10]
OpenSCAD/Solar_Beacon_Antenna_Spacer.stl
19.0 x 19.0 x 1.45

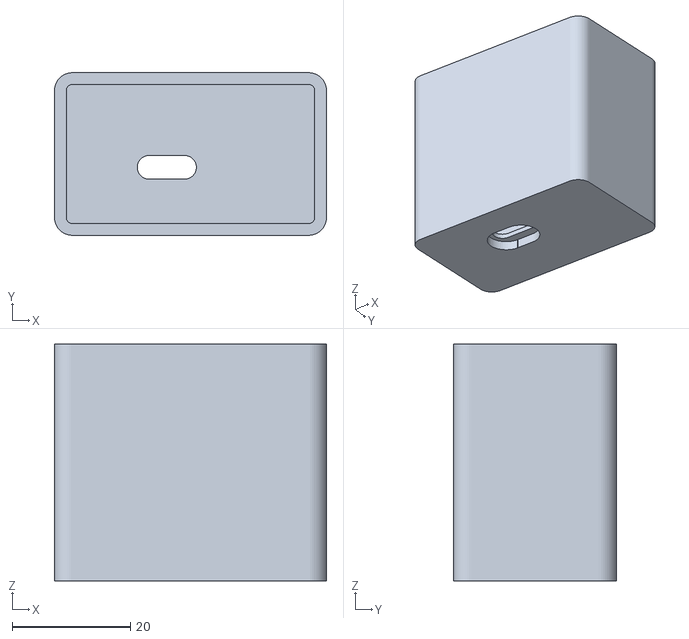
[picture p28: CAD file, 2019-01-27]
OpenSCAD/Solar_Beacon_Cover.stl
46.0 x 27.5 x 40.0

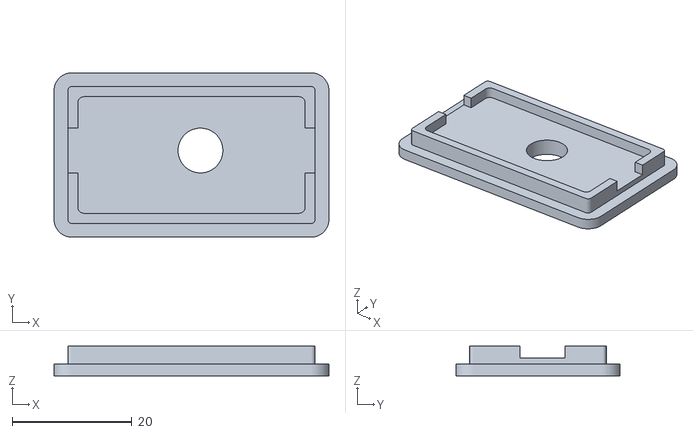
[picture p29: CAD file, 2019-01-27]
OpenSCAD/Solar_Beacon_Lid.stl
46.0 x 27.5 x 5.00

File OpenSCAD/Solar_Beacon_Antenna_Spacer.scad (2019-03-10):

// Simple Spacer for the Solar Beacon Antenna

$fn=50; // fragments
outer = 19.0; // Spacer outer diameter (mm)
inner = 6.75; // Diameter of hole for SMA connector
thickness = 3.0; // Total thickness of spacer and PCB
PCB_thickness = 1.55; // PCB thickness - subtracted from 'thickness' - change to 1.0mm if required

module spacer()
{
    difference() {
        cylinder(h=(thickness - PCB_thickness), r=(outer / 2));
        translate([0, 0, (0-(PCB_thickness / 2))])
            cylinder(h=(thickness), r=(inner / 2));
    }
}

spacer();

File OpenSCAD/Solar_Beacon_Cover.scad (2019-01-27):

// Simple Cover for the Iridium Solar Beacon with USB opening

$fn=50; // fragments
wall = 2.0; // wall thickness
end_wall = 3.0; // end wall thickness
internal_width = 42.0; // internal width (X) of the cover
internal_depth = 23.5; // internal depth (Y) of the cover
internal_height = 36.0; // internal height (Z) of the cover
lid_insert = 1.0; // extra height for the lid insert

internal_corner_radius = 1.0; // radius of the internal corner cylinder

usb_r = 2.0; // radius of the opening for the USB connector
usb_width = 10.0; // total width of the opening for the USB
usb_height = 1.0; // thickness of the opening for the USB connector
usb_recess_r = 4.0; // radius of the recess for the USB connector body
usb_recess_width = 12.0; // total width of the recess for the USB connector body
usb_x_offset = -4.0; // X offset of the USB connector
usb_y_offset = 2.25; // y offset of the USB connector

height = internal_height + end_wall + lid_insert; // cover external height (Z)
width = internal_width + (2 * wall); // cover external width (X)
depth = internal_depth + (2 * wall); // cover external depth (Y)

external_corner_radius = internal_corner_radius + wall; // external corner radius

module cover()
{
    translate([external_corner_radius, external_corner_radius, 0])
        minkowski() {
            cube([(width - (2 * external_corner_radius)), (depth - (2 * external_corner_radius)), (height / 2)]);
            cylinder(h=(height / 2), r=external_corner_radius);
        }
}

module void()
// Void will be higher than required to avoid zero thickness skin across opening
{
    translate([external_corner_radius, external_corner_radius, end_wall])
        minkowski() {
            cube([(internal_width - (2 * internal_corner_radius)), (internal_depth - (2 * internal_corner_radius)), (height / 2)]);
            cylinder(h=(height / 2), r=internal_corner_radius);
        }
}

module usb_opening_end_1()
// Cylinder is taller than it needs to be to avoid zero thickness skins
{
    translate([((usb_width / 2) - usb_r),0,usb_height]) {
        cylinder(h=end_wall,r=usb_r);
    }
}

module usb_opening_end_2()
// Cylinder is taller than it needs to be to avoid zero thickness skins
{
    translate([(0-((usb_width / 2) - usb_r)),0,usb_height]) {
        cylinder(h=end_wall,r=usb_r);
    }
}

module usb_opening_mid()
// Cube is taller than it needs to be to avoid zero thickness skins
{
    translate([(-0.5 * (usb_width - (2 * usb_r))), (-0.5 * (2 * usb_r)), usb_height]) {
        cube([(usb_width - (2 * usb_r)), (2 * usb_r), end_wall]);
    }
}

module usb_recess_end_1()
// Cylinder is taller than it needs to be to avoid zero thickness skins
{
    translate([((usb_recess_width / 2) - usb_recess_r), 0, (0 - usb_height)]) {
        cylinder(h=end_wall, r=usb_recess_r);
    }
}

module usb_recess_end_2()
// Cylinder is taller than it needs to be to avoid zero thickness skins
{
    translate([(0-((usb_recess_width / 2) - usb_recess_r)), 0, (0 - usb_height)]) {
        cylinder(h=end_wall, r=usb_recess_r);
    }
}

module usb_recess_mid()
// Cube is taller than it needs to be to avoid zero thickness skins
{
    translate([(-0.5 * (usb_recess_width - (2 * usb_recess_r))), (-0.5 * (2 * usb_recess_r)), (0 - usb_height)]) {
        cube([(usb_recess_width - (2 * usb_recess_r)), (2 * usb_recess_r), end_wall]);
    }
}

module usb()
{
    translate([((width / 2) + usb_x_offset), ((depth / 2) - usb_y_offset), 0]) {
        union() {
            usb_opening_end_1();
            usb_opening_end_2();
            usb_opening_mid();
            usb_recess_end_1();
            usb_recess_end_2();
            usb_recess_mid();
        }
    }
}

module finished_cover()
{
    difference() {
        cover();
        void();
        usb();
    }
}

finished_cover();

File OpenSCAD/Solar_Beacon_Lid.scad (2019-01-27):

// Simple Lid for the Iridium Solar Beacon Cover

$fn=50; // fragments
wall = 2.0; // cover wall thickness
thickness = 2.0; // lid end thickness
internal_width = 42.0; // internal width (X) of the cover
internal_depth = 23.5; // internal depth (Y) of the cover
gap = 0.3; // clearance gap (per side)
insert_height = 3.0; // extra height for the lid insert
internal_corner_radius = 1.0; // radius of the internal corner cylinder

sma_r = 3.75; // radius of the hole for the sma connector
sma_x_offset = 1.5; // X offset of the hole for the sma connector w.r.t. the X center of the void
sma_y_offset = 0.75; // y offset of the hole for the sma connector w.r.t. the Y center of the void
sma_wall_thickness = 3.0; // wall thickness around the SMA connectors

if (gap > internal_corner_radius) echo("Error! Gap cannot be greater than the internal corner radius!");

width = internal_width + (2 * wall); // lid external width (X)
depth = internal_depth + (2 * wall); // lid external depth (Y)

total_height = wall + insert_height; // total height of the lid

sma_x = (width / 2) + sma_x_offset; // x position of the sma connector
sma_y = (depth / 2) + sma_y_offset; // y position of the sma connector

external_corner_radius = internal_corner_radius + wall; // external corner radius

module outer()
{
    translate([external_corner_radius, external_corner_radius, 0])
        minkowski() {
            cube([(width - (2 * external_corner_radius)), (depth - (2 * external_corner_radius)), (thickness / 2)]);
            cylinder(h=(thickness / 2), r=external_corner_radius);
        }
}

module inner()
// Thicker than required to avoid zero thickness joints
{
    translate([external_corner_radius, external_corner_radius, 0])
        minkowski() {
            cube([(width - (2 * external_corner_radius)), (depth - (2 * external_corner_radius)), (total_height / 2)]);
            cylinder(h=(total_height / 2), r=(internal_corner_radius - gap));
        }
}

module recess()
// Thicker than required to avoid zero thickness joints
{
    translate([(internal_corner_radius + wall + wall), (internal_corner_radius + wall + wall), sma_wall_thickness])
        minkowski() {
            cube([(width - (2 * (wall + wall + internal_corner_radius))), (depth - (2 * (wall + wall + internal_corner_radius))), (total_height / 2)]);
            cylinder(h=(total_height / 2), r=internal_corner_radius);
        }
}

module lid()
{
    union() {
        outer();
        inner();
    }
}

module sma()
// Cylinder is taller than required to avoid zero thickness skins
{
    translate([sma_x, sma_y, -1]) {
        cylinder(h=(total_height + 2),r=sma_r);
    }
}

module pcb_slot()
// Cube is taller amd wider than required to avoid zero thickness skins
{
    translate([0, (sma_y - sma_r), sma_wall_thickness]) {
        cube([width, (sma_r * 2), total_height]);
    }
}

module finished_lid()
{
    difference() {
        lid();
        sma();
        recess();
        pcb_slot();
    }
}

finished_lid();

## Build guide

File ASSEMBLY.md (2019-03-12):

# Iridium 9603N Solar Beacon Assembly Instructions

Here are the assembly instructions for the Iridium 9603N Solar Beacon:

### Blank PCB

Start by having the blank PCBs manufactured. If you are based in the UK or Europe, I can recommend
[Multi-CB](https://www.multi-circuit-boards.eu/en/index.html) who can manufacture PCBs in 1-8 working days and
can process the Eagle .brd file direct - there's no need to generate Gerber files.

My recommended options are:
- Layers: 2 layers
- Format: single pieces
- Surface finish: chemical gold (ENIG)
- Material: FR4, 1.55mm
- Cu layers: 35um
- Solder stop: both sides, green
- Marking print: both sides, white

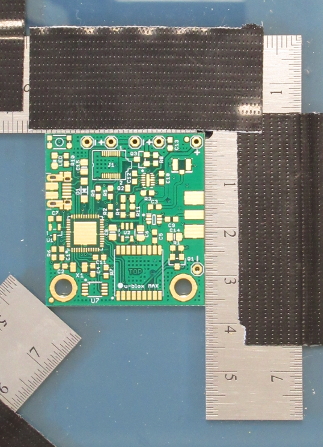
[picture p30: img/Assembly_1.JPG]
Assembly_1


### Add solder paste

Multi-CB can also provide you with a solder paste (SMD) stencil for the PCB. My recommended options are:
- SMD stencil for: top layer
- Make the Y dimension 20mm longer than the PCB itself to allow you to fix it down with tape
- Type: custom
- Pad reduction: yes, 10%
- Thickness: 100um
- Existing fiducials: lasered through
- Text type: half lasered
- Double-sided brushing: yes

I secure the blank PCB onto a flat work surface by locating it between two engineer's squares. I use a sheet of toughened glass
as the work surface as it is both very flat and easy to clean.

Use the two round fiducials to line up the stencil with the PCB. Secure the stencil with tape.

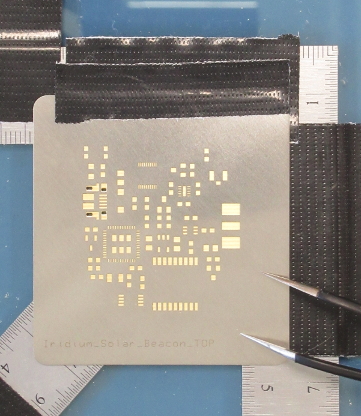
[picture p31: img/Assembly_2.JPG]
Assembly_2


Apply solder paste close to the component cut-outs and then scrape the paste over the stencil using a knife blade
or a similar straight edge. Take appropriate safety precautions when working with solder paste - particularly if you are using
tin-lead solder instead of lead-free.

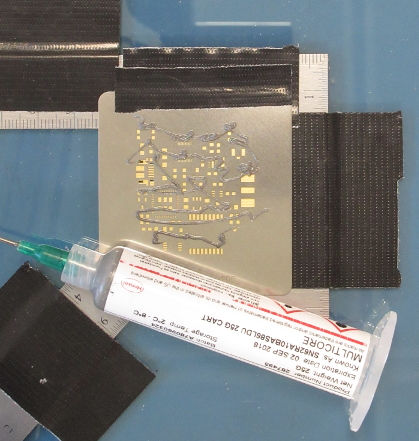
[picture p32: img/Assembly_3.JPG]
Assembly_3


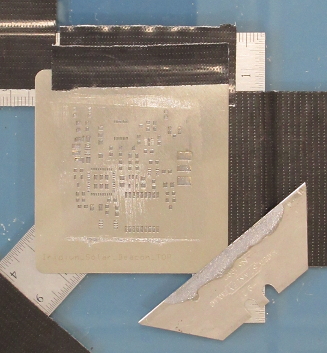
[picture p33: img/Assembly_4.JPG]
Assembly_4


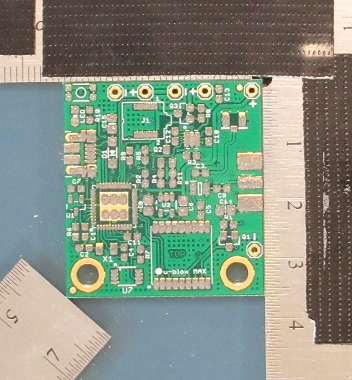
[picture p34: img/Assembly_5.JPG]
Assembly_5


### Position the surface mount components

Position the components onto the blobs of solder paste using tweezers. A magnifier lamp or a USB microscope will
help you place the components in the correct position. J1 - the 20-way Samtec connector - is probably the trickiest
component to position. Take extra time to make sure the legs are centered accurately on the pads.
You may find the [SMT_Component_Placer](https://github.com/PaulZC/SMT_Component_Placer) useful.

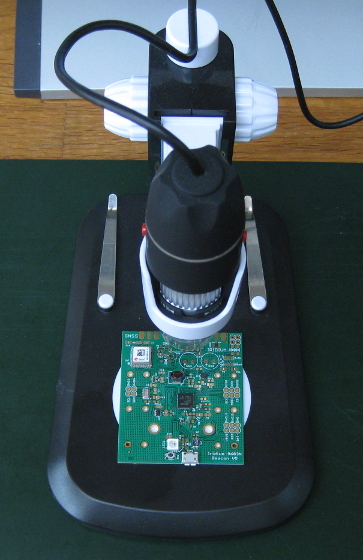
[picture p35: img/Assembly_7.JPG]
Assembly_7


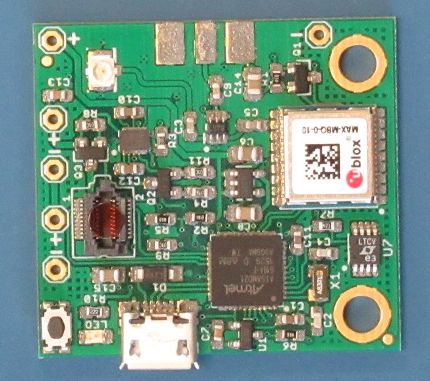
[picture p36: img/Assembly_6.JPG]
Assembly_6


### Reflow the surface mount components

Use a reflow oven to heat the circuit board to the correct temperatures to melt the solder. A reflow oven doesn't need to be
expensive. The one shown below was assembled from:

- Quest 9L 800W mini-oven
- Inkbird PID temperature controller and 40A solid state relay
- Type K thermocouple

Several people have published good reflow oven construction guides, including [this one](http://www.die4laser.com/toaster/index.html).

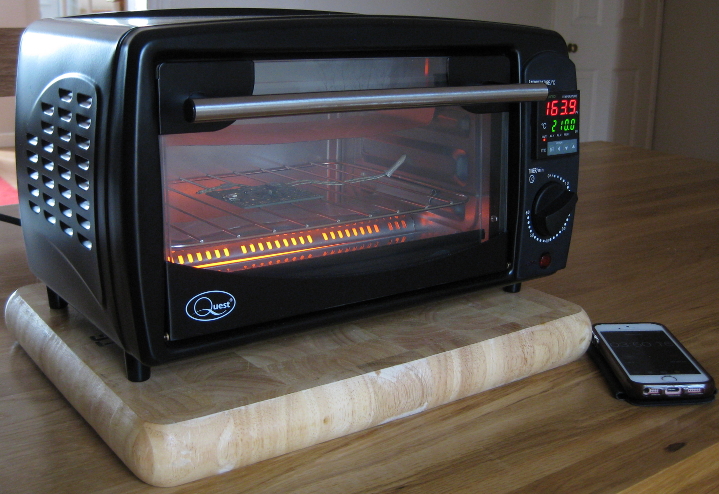
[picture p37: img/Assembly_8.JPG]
Assembly_8


Use the correct temperature profile for your solder paste, but you won't go far wrong with 160C for four minutes, followed by
210C for one minute, followed by a cool-down with the door open. Use a flashlight to check that the solder has melted across
the whole PCB at 210C. Hold the temperature at 210C a little longer if some of the solder paste still appears 'gray' instead of 'silver'.

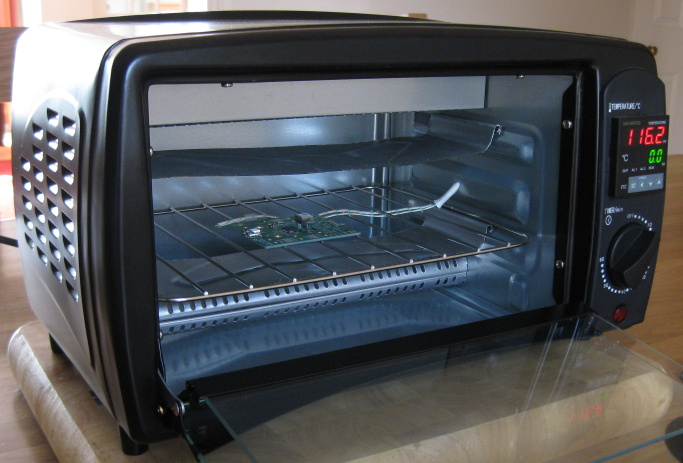
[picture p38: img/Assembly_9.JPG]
Assembly_9


### Check for shorts

Carefully examine all the solder joints and correct any shorts you find.

The 'trick' to removing a short is to add more solder or solder paste and then to use
copper solder braid or wick to remove all the solder in one go.

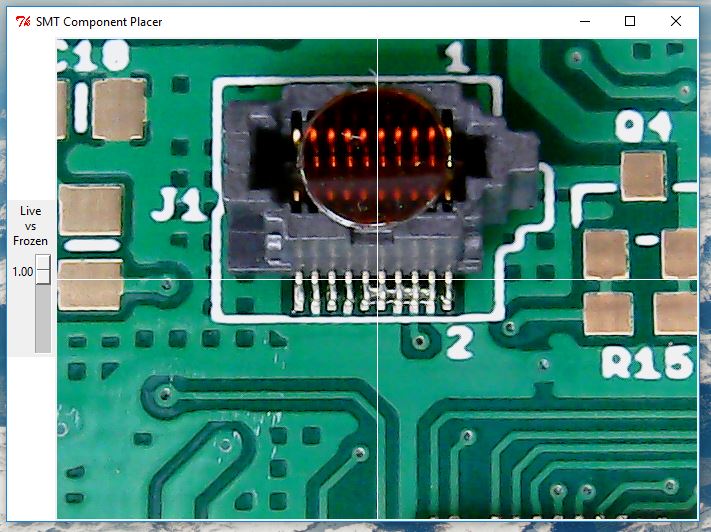
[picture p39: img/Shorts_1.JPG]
Shorts_1


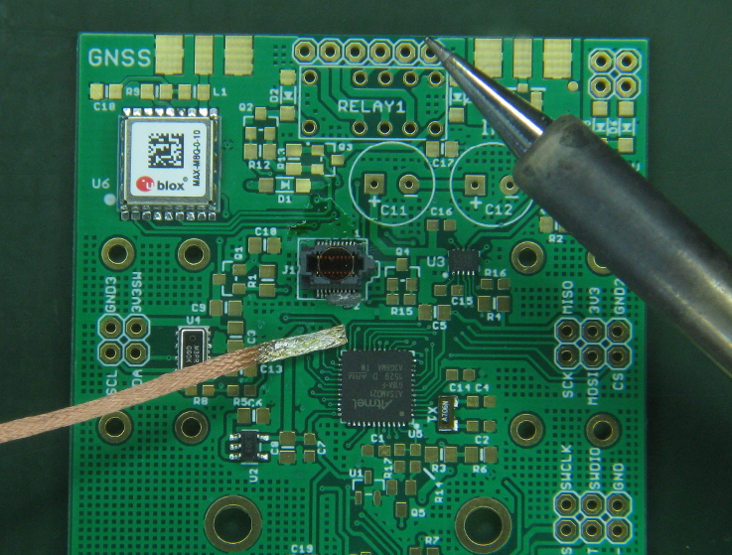
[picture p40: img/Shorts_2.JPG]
Shorts_2


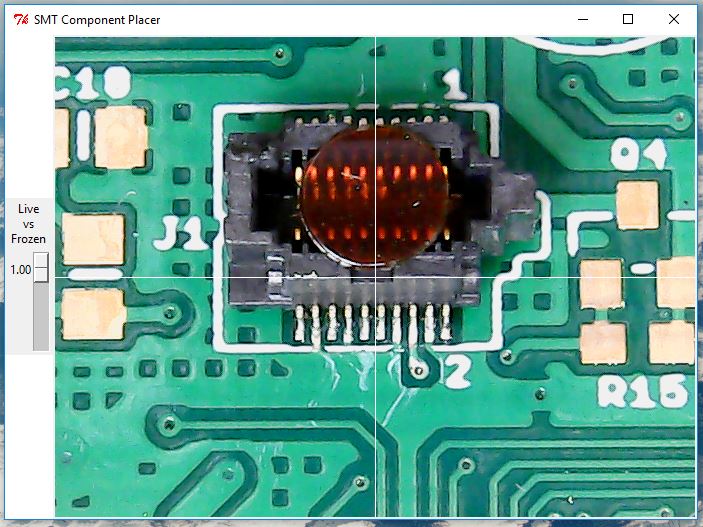
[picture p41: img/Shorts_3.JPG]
Shorts_3


Solder any remaining surface mount components by hand and then use a cotton swab dipped in Iso-Propyl Alcohol
(IPA / Propanol / rubbing alcohol) to remove any flux residue.

### Press-in nuts

The Iridium 9603N module is held in place by two 2-56 screws. The threaded 2-56 press-in nuts now need to be pressed into the rear of the
PCB. These are McMaster part number 95117A411. The nuts are best pressed into place using an arbor press.

### Add the non-surface mount components

The non-surface mount components (super capacitors, SMA conector) can now be soldered in by hand.

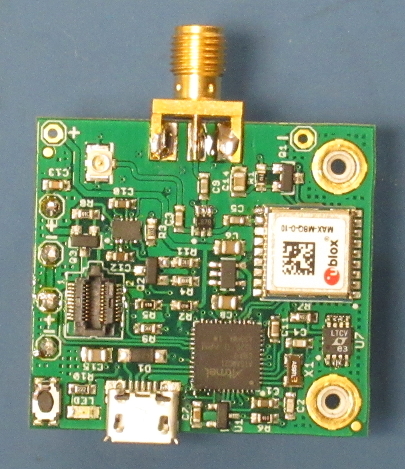
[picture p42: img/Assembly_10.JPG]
Assembly_10


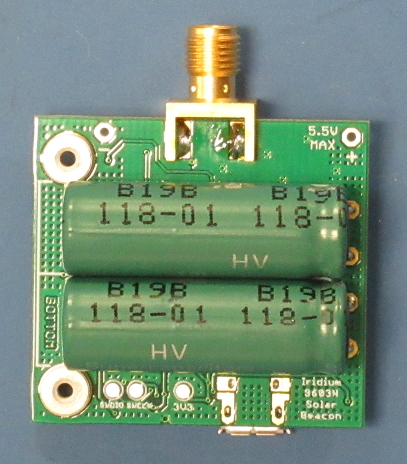
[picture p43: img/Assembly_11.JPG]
Assembly_11


### Install the bootloader

The SAMD21G18A processor now needs to be configured with a bootloader using a J-Link programmer or similar. See
[How do I install the ATSAMD21G18 Bootloader](https://github.com/PaulZC/Iridium_9603N_Solar_Beacon/blob/master/LEARN.md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)
for further details.

Assembly_12

### Test the PCB

Before connecting the Iridium 9603N, it is a good idea to test the completed PCB. The [Arduino](https://github.com/PaulZC/Iridium_9603N_Solar_Beacon/tree/master/Arduino)
directory contains a sketch called Iridium_9603N_Solar_Beacon_Test which will test all of the components on the PCB for you. Messages are displayed
on the Arduino IDE Serial Monitor as each test is passed.

### Install the Iridium 9603N module

Take appropriate ESD precautions throughout and especially when handling the 9603N module.

Connect the 9603N to the beacon PCB using a HIROSE (HRS) u.FL-u.FL cable or similar. The cable needs to be 50 Ohm and approximately 25mm long.

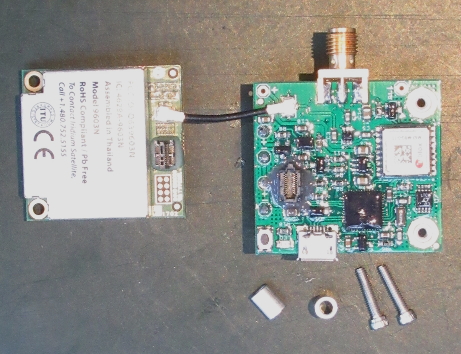
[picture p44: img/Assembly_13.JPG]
Assembly_13


Carefully fold the 9603N module over onto the PCB, insert the 20-way connector into the Samtec socket, then secure the module using:
- two 4.5mm OD x 6mm spacers (McMaster 94669A100)
- two 2-56 x 7/16" screws (McMaster 92185A081)

Assembly_15

Screw the antenna onto the SMA connector

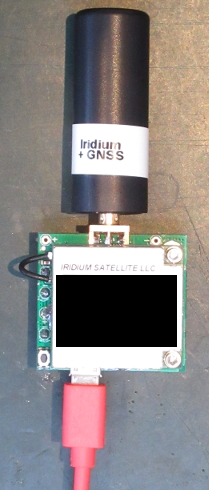
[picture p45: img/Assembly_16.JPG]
Assembly_16


### Retest the PCB

Now that the 9603N has been installed, retest the completed PCB using the [Arduino test code](https://github.com/PaulZC/Iridium_9603N_Solar_Beacon/tree/master/Arduino).

### Secure J1 with Epoxy

I recommend securing J1 to the PCB with a small amount of epoxy to make it more robust. 3M Scotch-Weld 2216 is an ideal choice as it remains slightly flexible when cured.
You will need to temporarily remove the 9603N while you apply the epoxy. Apply the mixed epoxy around the body and legs of J1 using a toothpick,
taking great care to keep the epoxy clear of the connector opening and pins. Make sure the epoxy is fully cured before re-installing the 9603N.

### Lacquer the PCB

I recommend giving the PCB a coat of lacquer, especially if you are intending to use it to track a balloon flight.
You will need to temporarily remove the 9603N while you apply the lacquer. Cover all of the surface mount components with
[Acrylic Protective Lacquer (conformal coating)](https://uk.rs-online.com/web/p/conformal-coatings/3217324/) except: J1, SW1, CON1, CON2, IO pads.
Keep the top of the MAX-M8Q clear of lacquer too as its package is only just thin enough to fit under the 9603N.

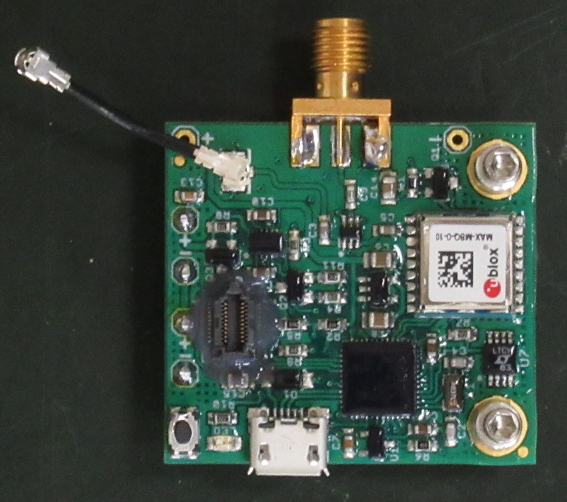
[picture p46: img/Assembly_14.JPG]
Assembly_14


Once the lacquer is dry, re-attach the 9603N and your board is ready for use.

### Assemble and attach the solar panels

The [Eagle](https://github.com/PaulZC/Iridium_9603N_Solar_Beacon/tree/master/Eagle) directory contains the schematic and pcb design file for
the Solar Panel Support.

Solder two MBR120 diodes onto the PCB pads. In this photo the diode cathodes point down.

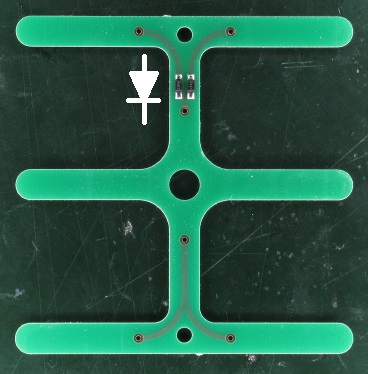
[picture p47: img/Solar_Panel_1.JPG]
Solar_Panel_1


Cut six pieces of double sided foam tape and stick them onto the PCB fingers. I recommend using good quality acrylic adhesive tape,
e.g. 3M VHB Tape 4941P.

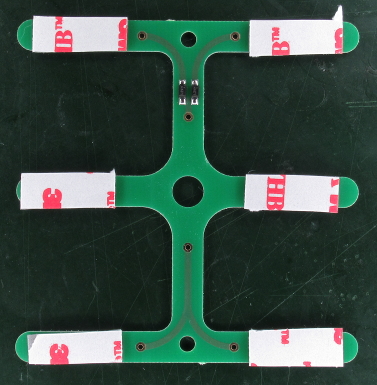
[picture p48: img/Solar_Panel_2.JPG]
Solar_Panel_2


Stick the two solar panels to the foam tape, paying close attention to the panel orientation. In this photo both panels are oriented so the minus
connections are at the bottom.

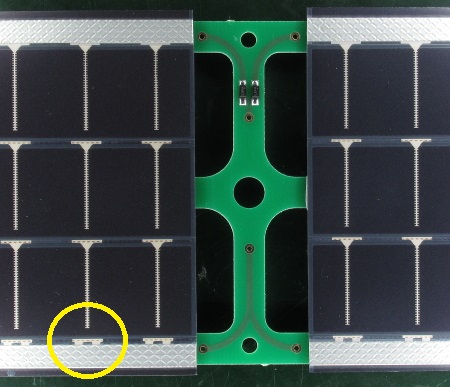
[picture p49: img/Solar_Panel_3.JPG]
Solar_Panel_3


Take four header pins and bend one end of each through 90 degrees. Solder these in position, applying solder to both sides of the PCB for added
strength.

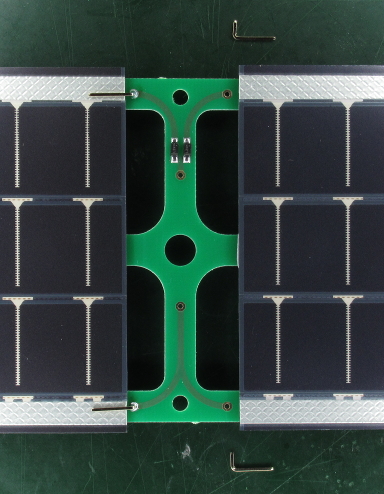
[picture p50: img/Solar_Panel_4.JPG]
Solar_Panel_4


Solder the pins to the panels; apply heat and flow solder onto each pin until the top plastic coat on the panel melts and the solder flows onto the
electrode beneath. Take care not to apply excessive heat or you may damage the panel.

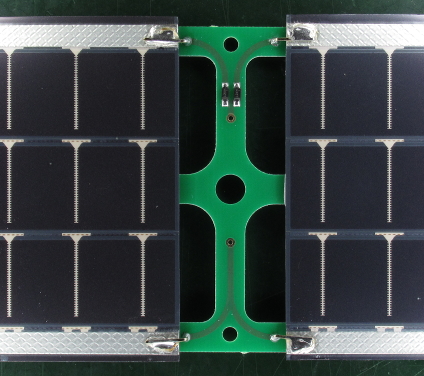
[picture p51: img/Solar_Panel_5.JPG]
Solar_Panel_5


Solder two more 90 degree header pins through the + and - pads on the beacon PCB such that the pins point parallel to the SMA connector.
Apply solder to both sides of the PCB for added strength.

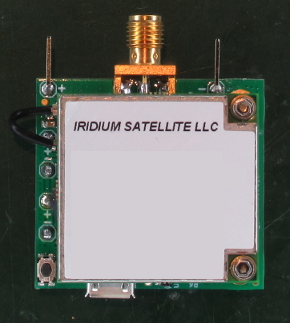
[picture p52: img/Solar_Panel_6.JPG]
Solar_Panel_6


Pass the SMA connector through the hole in the center of the solar panel support and locate the two pins through the matching pads.
Place a 3D-printed antenna spacer over the SMA connector and screw the antenna into position, taking care not to bend the pins.
Finally, solder the pins to the solar panel support applying solder to both sides of the PCB for added strength.

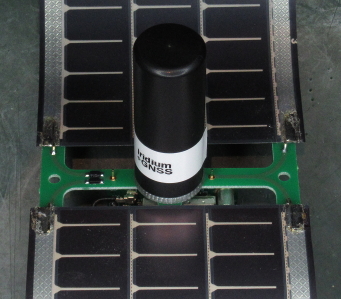
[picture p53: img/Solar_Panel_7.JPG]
Solar_Panel_7


The [OpenSCAD](https://github.com/PaulZC/Iridium_9603N_Solar_Beacon/tree/master/OpenSCAD) directory contains the .stl and .scad files for the
antenna spacer. The spacer is the correct thickness for a 1.55mm solar panel support. You will need to edit the .scad file to produce a spacer
for (e.g.) a 1.0mm solar panel support.

### The Small Print

This project is distributed under a Creative Commons Attribution + Share-alike (BY-SA) licence.
Please refer to section 5 of the licence for the "Disclaimer of Warranties and Limitation of Liability".

Enjoy!

**_Paul_**

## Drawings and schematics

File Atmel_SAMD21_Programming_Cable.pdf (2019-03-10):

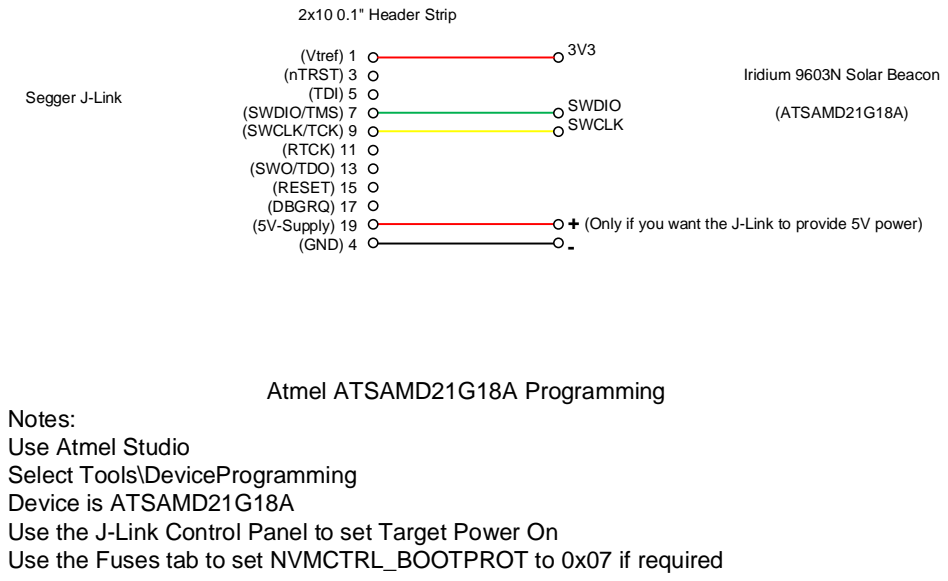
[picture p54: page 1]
Segger J-Link; Atmel ATSAMD21G18A Programming; (Vtref) 1 (nTRST) 3 (TDI) 5 (SWDIO/TMS) 7 (SWCLK/TCK) 9 (RTCK) 11 (SWO/TDO) 13 (RESET) 15 (DBGRQ) 17 (5V-Supply) 19 (GND) 4; (ATSAMD21G18A); 2x10 0.1" Header Strip; SWDIO SWCLK

Iridium 9603N Solar Beacon

+ (Only if you want the J-Link to provide 5V power)

Notes:
Use Atmel Studio
Select Tools\DeviceProgramming
Device is ATSAMD21G18A
Use the J-Link Control Panel to set Target Power On
Use the Fuses tab to set NVMCTRL_BOOTPROT to 0x07 if required

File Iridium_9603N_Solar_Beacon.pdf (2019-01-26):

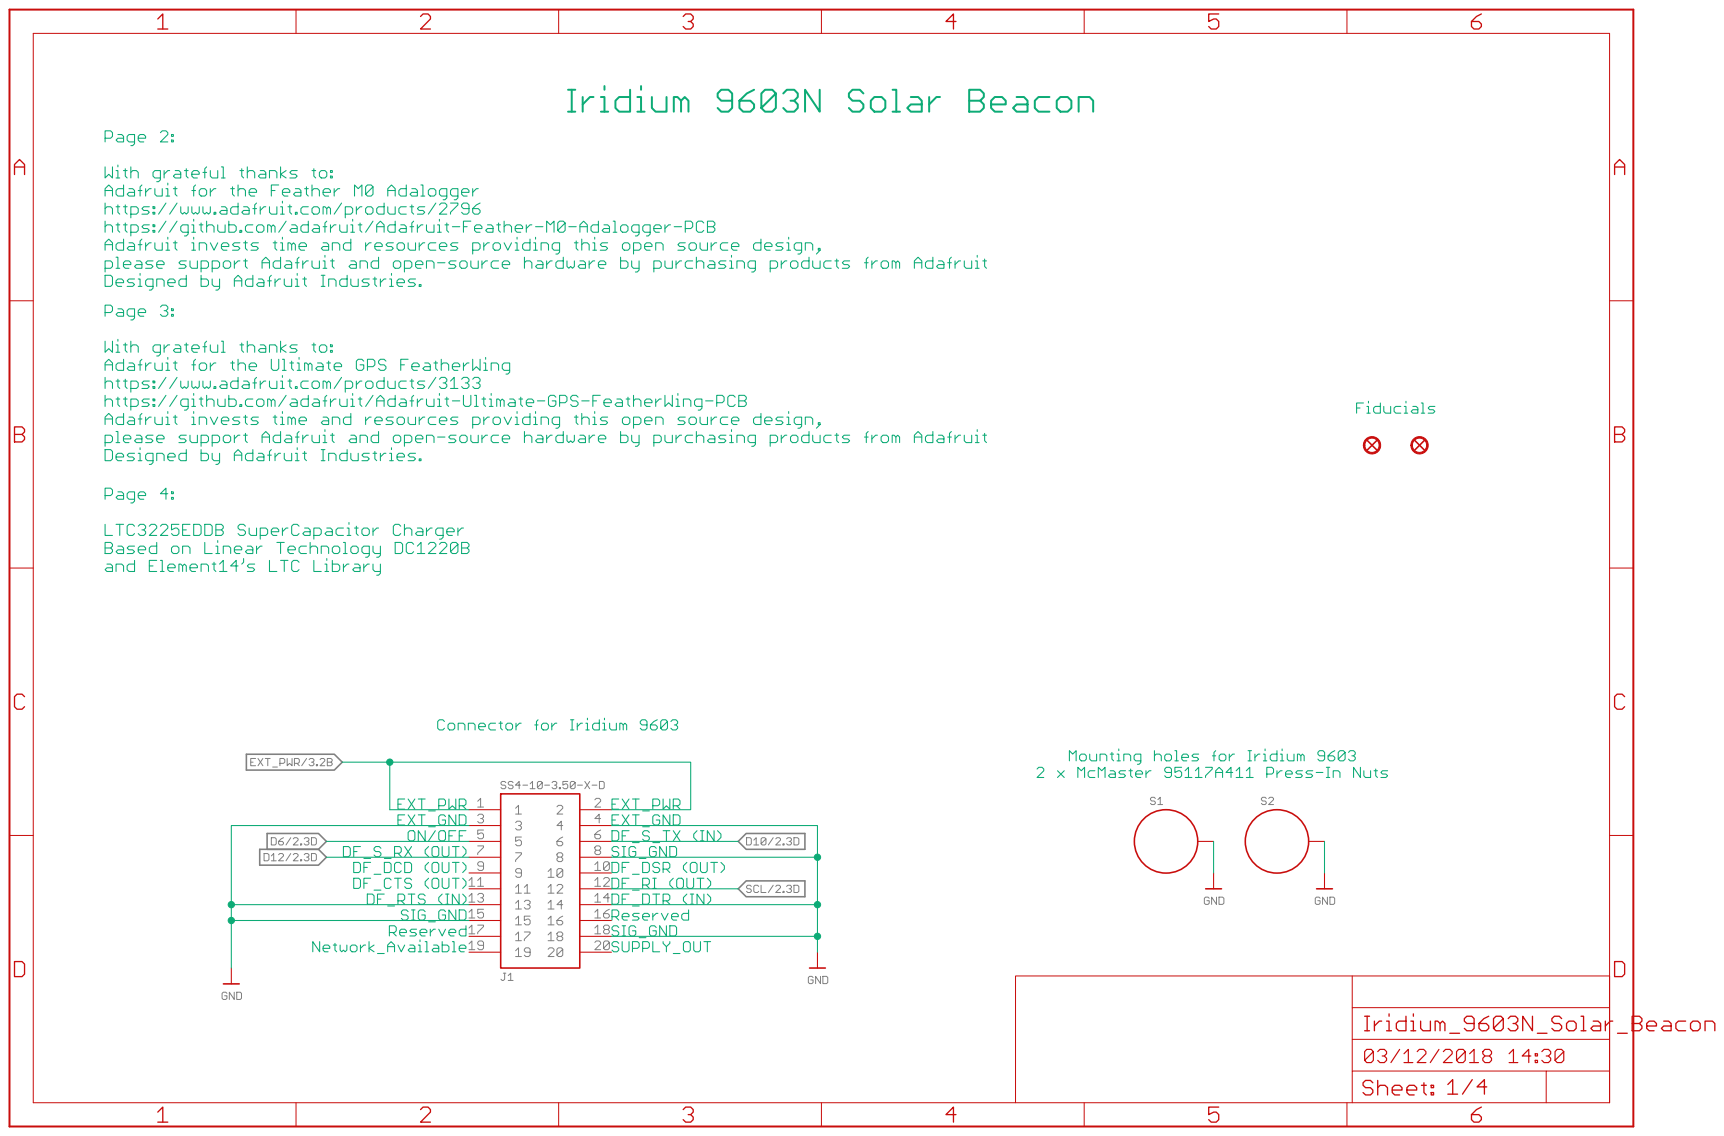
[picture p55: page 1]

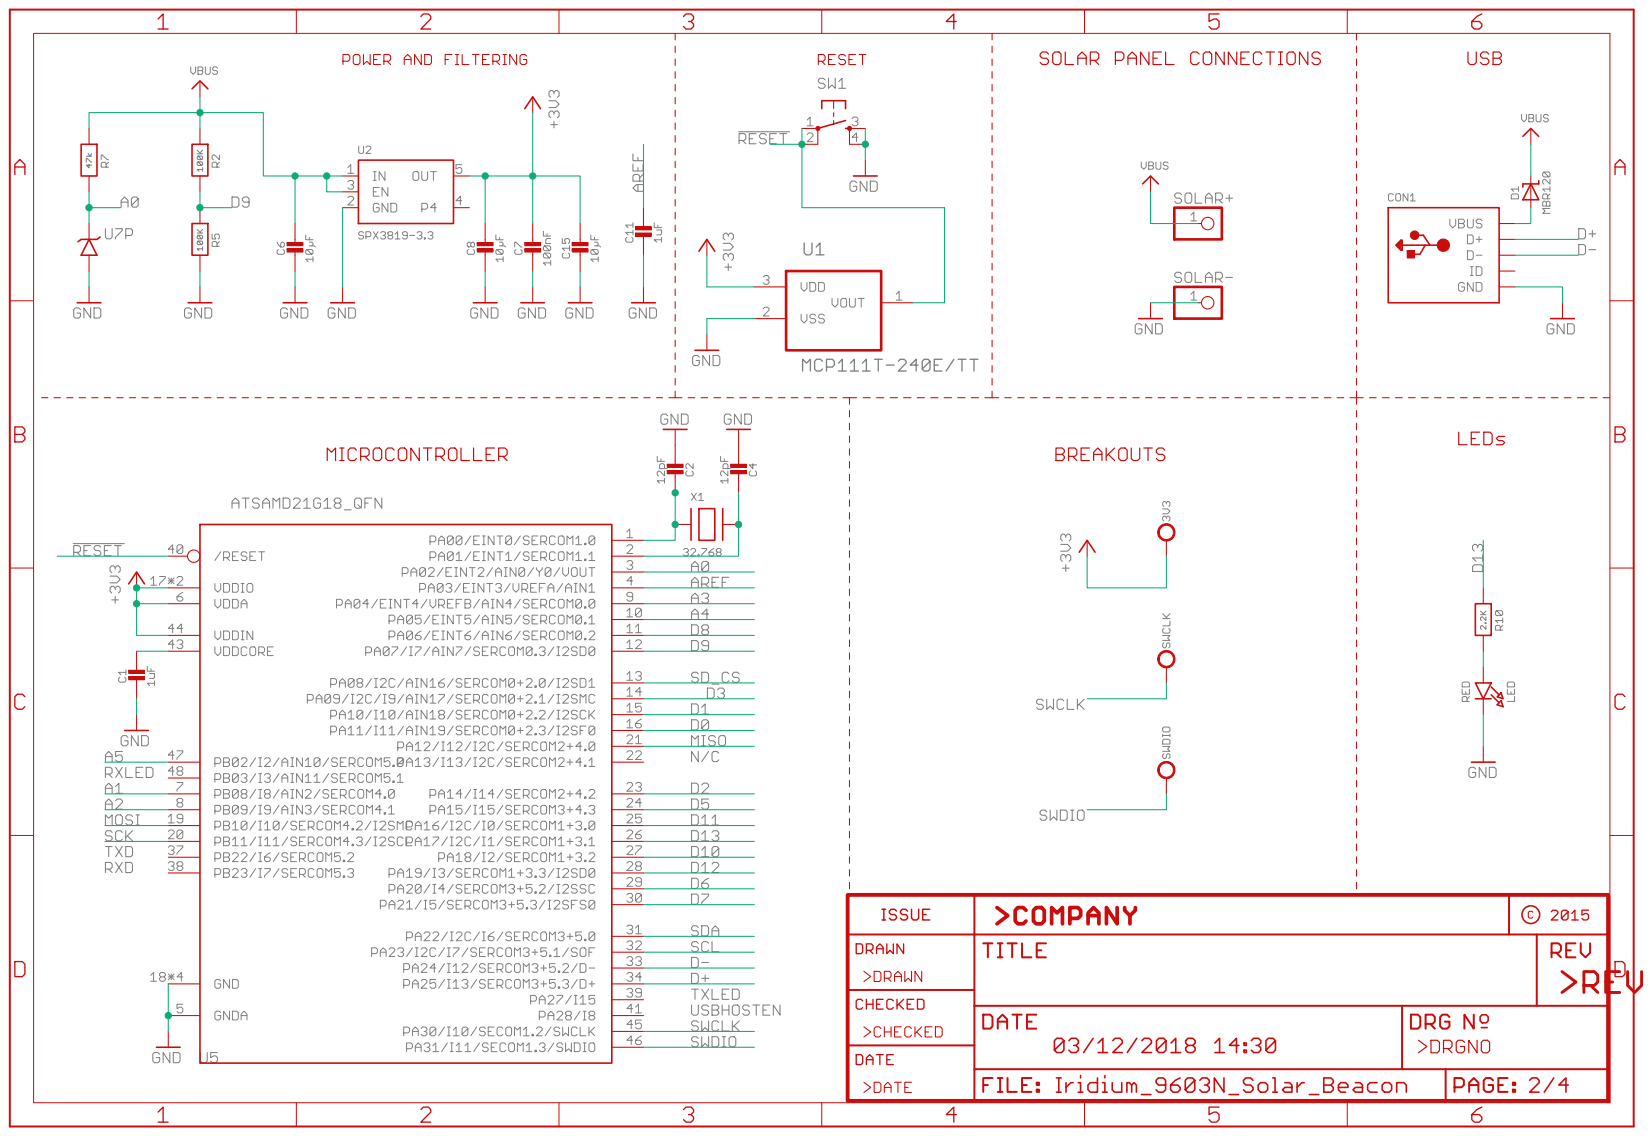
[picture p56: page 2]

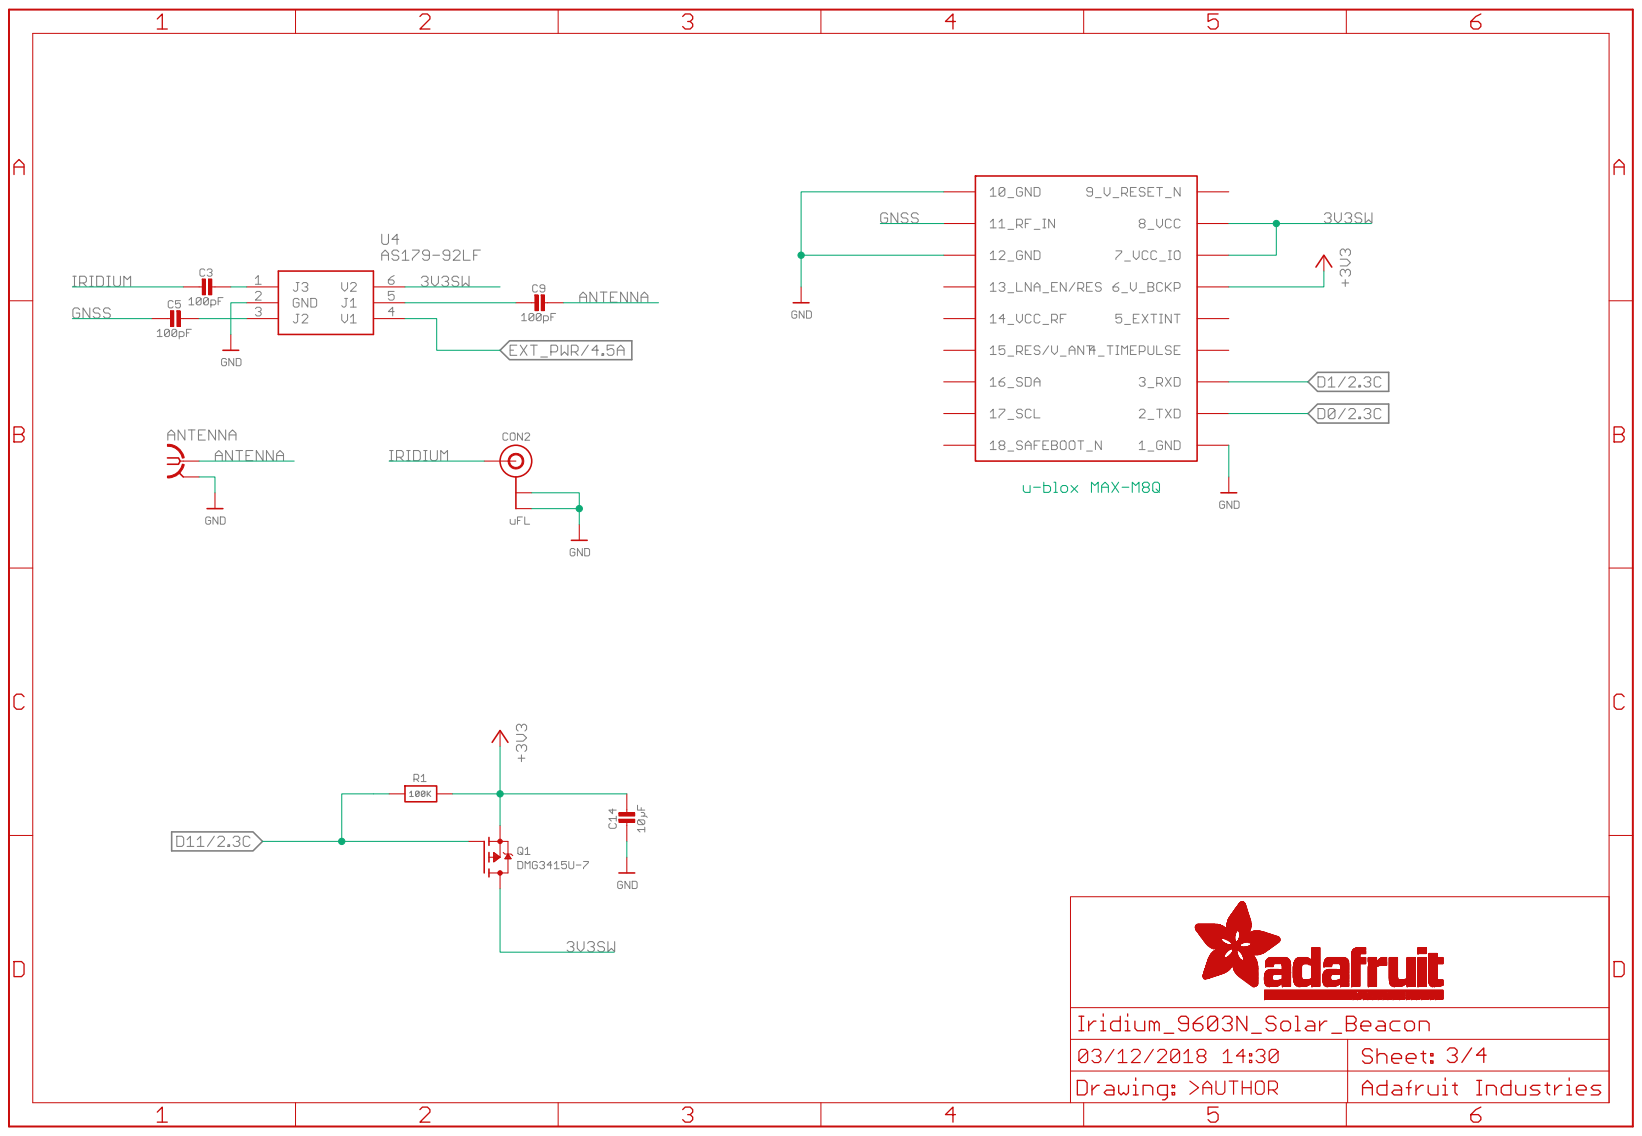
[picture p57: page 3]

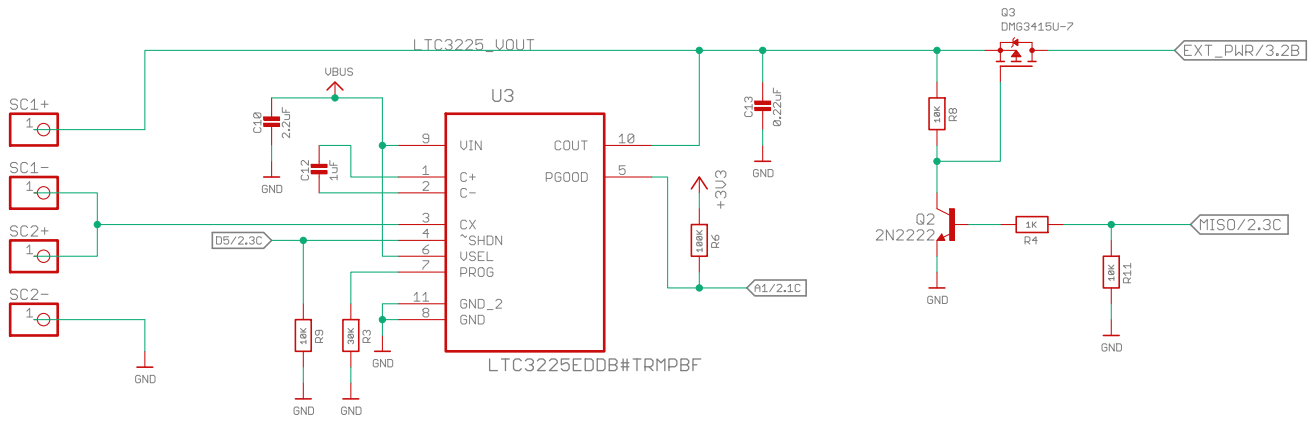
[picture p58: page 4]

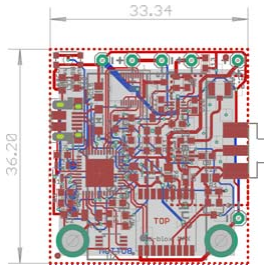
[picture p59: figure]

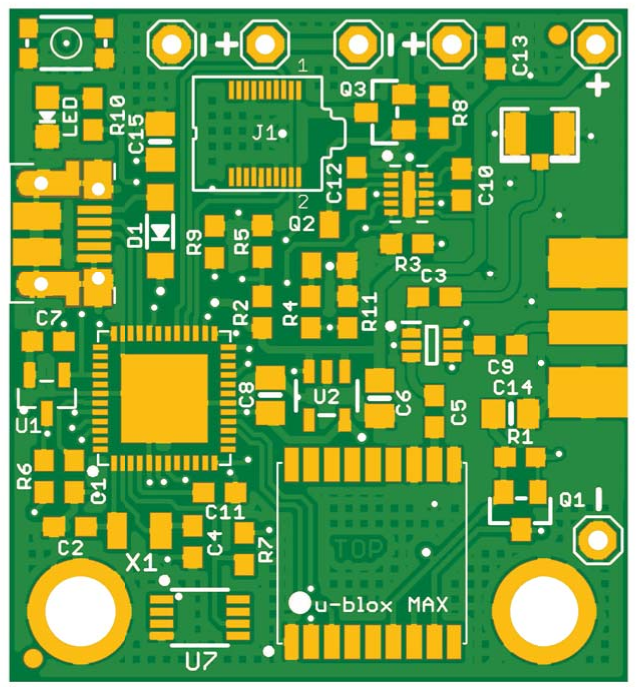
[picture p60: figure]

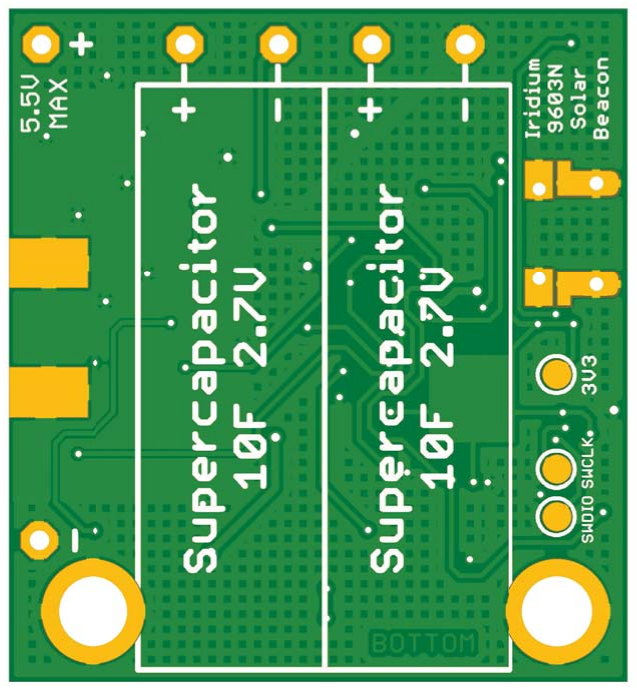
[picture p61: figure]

Part | X | Y | Angle Package | Value | Manufacturer | Manufacturer Part No

Farnell
Part No Mouser Part No

McMaster
Part No Description

Dimensions 33.34 36.20

Fiducials - for solder paste mask alignment:

FD1 | 1.27 | 1.27 | 0 | | | | | | Fiducial 1mm
FD2 | 29.62 34.80 0 | Fiducial 1mm

Surface Mount Components:

C1 | 3.46 | 11.05 270 | 0603 | 1uF | Walsin | 0603X105K100CT | 2496916 | MultiLayer Ceramic Capacitor; 1uF; 10V; 0603; X5R
C2 | 3.24 | 8.35 | 180 | 0603 | 12pF | Walsin | 0603N120J500CT | 2496884 | MultiLayer Ceramic Capacitor; 12pF; 50V; 0603
C3 | 22.86 20.7 | 0 | 0603 | 120pF | Walsin | 0603B121K500CT | 2524820 | MultiLayer Ceramic Capacitor; 120pF; 50V; 0603
C4 | 9.94 | 7.56 | 270 | 0603 | 12pF | Walsin | 0603N120J500CT | 2496884 | MultiLayer Ceramic Capacitor; 12pF; 50V; 0603
C5 | 22.86 14.54 270 | 0603 | 120pF | Walsin | 0603B121K500CT | 2524820 | MultiLayer Ceramic Capacitor; 120pF; 50V; 0603
C6 | 19.94 15.24 270 | 0805 | 10µF | Walsin | 0805F106Z100CT | 2496998 | MultiLayer Ceramic Capacitor; 10uF; 10V; 0805
C7 | 2.06 | 18.29 180 | 0603 | 100nF | Murata | GRM188R71H104JA93D 2688523 | MultiLayer Ceramic Capacitor; 0.1uF; 50V; 0603; X7R
C8 | 14.1 | 15.4 | 90 | 0805 | 10µF | Walsin | 0805F106Z100CT | 2496998 | MultiLayer Ceramic Capacitor; 10uF; 10V; 0805
C9 | 26.42 18.1 | 180 | 0603 | 120pF | Walsin | 0603B121K500CT | 2524820 | MultiLayer Ceramic Capacitor; 120pF; 50V; 0603
C10 | 24.32 26.8 | 270 | 0603 | 1uF | Walsin | 0603X105K100CT | 2496916 | MultiLayer Ceramic Capacitor; 1uF; 10V; 0603; X5R
C11 | 11.37 10.19 0 | 0603 | 1uF | Walsin | 0603X105K100CT | 2496916 | MultiLayer Ceramic Capacitor; 1uF; 10V; 0603; X5R
C12 | 18.7 | 26.86 270 | 0603 | 1uF | Walsin | 0603X105K100CT | 2496916 | MultiLayer Ceramic Capacitor; 1uF; 10V; 0603; X5R
C13 | 26.13 33.85 270 | 0603 | 100nF | Murata | GRM188R71H104JA93D 2688523 | MultiLayer Ceramic Capacitor; 0.1uF; 50V; 0603; X7R
C14 | 26.99 14.41 0 | 0805 | 10µF | Walsin | 0805F106Z100CT | 2496998 | MultiLayer Ceramic Capacitor; 10uF; 10V; 0805
C15 | 8.19 | 29.08 90 | 0805 | 10µF | Walsin | 0805F106Z100CT | 2496998 | MultiLayer Ceramic Capacitor; 10uF; 10V; 0805
CON1 | 2.99 | 24.13 270 | Micro_USB | Amphenol_FCI | 10103594 | 2293752 | Amphenol FCI 10103594 Micro USB Type B
CON2 | 28.58 28.77 270 | uFL | uFL | Hirose | U.FL-R-SMT(01) | 3908021 | HIROSE U.FL-R-SMT(01); U.FL Coaxial; Straight Jack; 50 ohm
D1 | 8.19 | 24.26 90 | SOD-123 | MBR120 | ON SEMICONDUCTOR MBR120VLSFT1G | 1431044 | Schottky Rectifier; 20V; 1A; SOD-123
J1 | 13.81 29.53 0 | SS4-10-3.50 | Samtec | SS4-10-3.50-L-D-K-TR | 2085336 | Samtec SS4-10-3.50-L-D-K-TR
LED | 2.03 | 30.42 180 | 2.0x1.25 | RED | Wurth Electronik | 150080RS75000 | 2322077 710-150080RS75000 | LED; Red; 20mA; 2V; 2.0x1.25mm
Q1 | 27.53 9.21 | 180 | SOT23 | DMG3415U-7 | Diodes Inc. | DMG3415U-7 | 1843688 | MOSFET; P Channel; SOT23-WIDE
Q2 | 17.24 23.53 0 | SOT23 | 2N2222 | Fairchild | MMBT2222A | 9846700 | Bipolar (BJT) Single Transistor, NPN, 40 V, 350 mW, 1 A
Q3 | 20.22 30.67 90 | SOT23 | DMG3415U-7 | Diodes Inc. | DMG3415U-7 | 1843688 | MOSFET; P Channel; SOT23-WIDE
R1 | 27.5 | 12.07 180 | 0603 | 100K | Multicomp | MCWR06X1003FTL | 2447226 | Chip Resistor; Thick Film; 100k; 50V; 0603; 100mW
R2 | 13.65 19.88 90 | 0603 | 100K | Multicomp | MCWR06X1003FTL | 2447226 | Chip Resistor; Thick Film; 100k; 50V; 0603; 100mW
R3 | 21.4 | 23.62 180 | 0603 | 30K | Multicomp | MCWR06X3002FTL | 2447333 | Chip Resistor; Thick Film; 30k; 50V; 0603; 100mW
R4 | 16.26 19.88 90 | 0603 | 1K | Multicomp | MCWR06X1001FTL | 2447272 | Chip Resistor; Thick Film; 1k; 50V; 0603; 100mW
R5 | 13.65 23.75 90 | 0603 | 100K | Multicomp | MCWR06X1003FTL | 2447226 | Chip Resistor; Thick Film; 100k; 50V; 0603; 100mW
R6 | 1.84 | 11.05 270 | 0603 | 100K | Multicomp | MCWR06X1003FTL | 2447226 | Chip Resistor; Thick Film; 100k; 50V; 0603; 100mW
R7 | 12.7 | 7.18 | 270 | 0603 | 47k | Multicomp | MCWR06X4702FTL | 2447376 | Chip Resistor; Thick Film; 47k; 50V; 0603; 100mW
R8 | 23.11 30.67 270 | 0603 | 10K | Multicomp | MCWR06X1002FTL | 2447230 | Chip Resistor; Thick Film; 10k; 50V; 0603; 100mW
R9 | 11.08 23.72 90 | 0603 | 10K | Multicomp | MCWR06X1002FTL | 2447230 | Chip Resistor; Thick Film; 10k; 50V; 0603; 100mW
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

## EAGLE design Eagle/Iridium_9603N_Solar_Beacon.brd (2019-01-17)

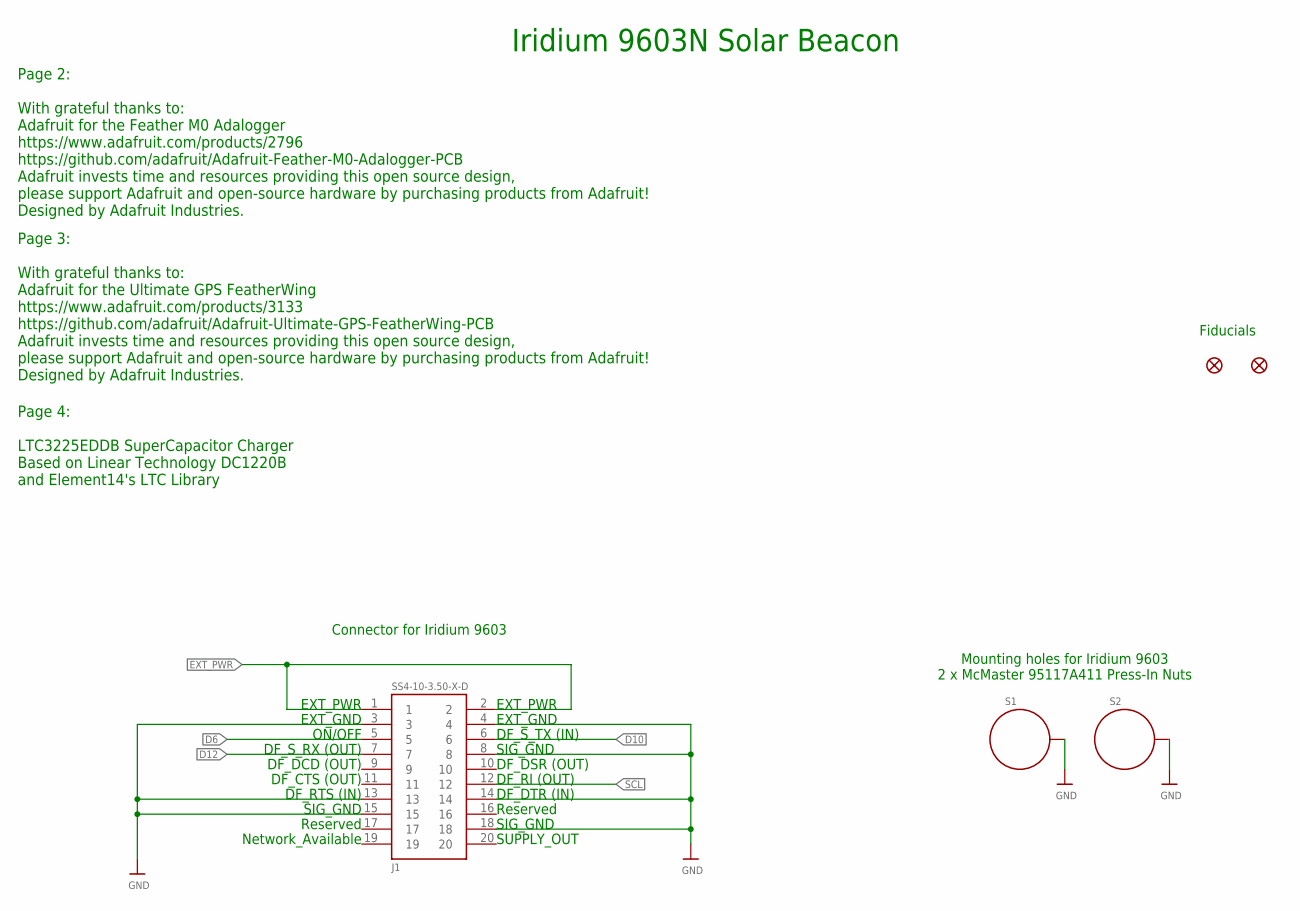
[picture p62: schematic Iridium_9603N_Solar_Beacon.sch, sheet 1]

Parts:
FD1, FD2: FIDUCIAL1X2; FIDUCIAL-1X2
J1: SS4-10-3.50-X-D
S1, S2: STANDOFF_ELECTRICALMCMASTER-95117A411; STANDOFF-ELECTRICAL-MCMASTER-95117A411

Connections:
D6: J1.5; also elsewhere on the board
D10: J1.6; also elsewhere on the board
D12: J1.7; also elsewhere on the board
EXT_PWR: J1.1, J1.2; also elsewhere on the board
GND: J1.3, J1.4, J1.8, J1.13, J1.14, J1.15, J1.18, S1.P1, S2.P1; also elsewhere on the board
SCL: J1.12; also elsewhere on the board

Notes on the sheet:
Connector for Iridium 9603
Mounting holes for Iridium 9603 2 x McMaster 95117A411 Press-In Nuts
Iridium 9603N Solar Beacon
Page 2: With grateful thanks to: Adafruit for the Feather M0 Adalogger https://www.adafruit.com/products/2796 https://github.com/adafruit/Adafruit-Feather-M0-Adalogger-PCB Adafruit invests time and resources providing this open source design, please support Adafruit and open-source hardware by purc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
Page 3: With grateful thanks to: Adafruit for the Ultimate GPS FeatherWing https://www.adafruit.com/products/3133 https://github.com/adafruit/Adafruit-Ultimate-GPS-FeatherWing-PCB Adafruit invests time and resources providing this open source design, please support Adafruit and open-source hardware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
EXT_PWR
EXT_GND
ON/OFF
DF_S_RX (OUT)
DF_DCD (OUT)
DF_CTS (OUT)
DF_RTS (IN)
SIG_GND
Reserved
Network_Available
DF_S_TX (IN)
DF_DSR (OUT)
DF_RI (OUT)
DF_DTR (IN)
SUPPLY_OUT
Page 4: LTC3225EDDB SuperCapacitor Charger Based on Linear Technology DC1220B and Element14's LTC Library
Fiducials

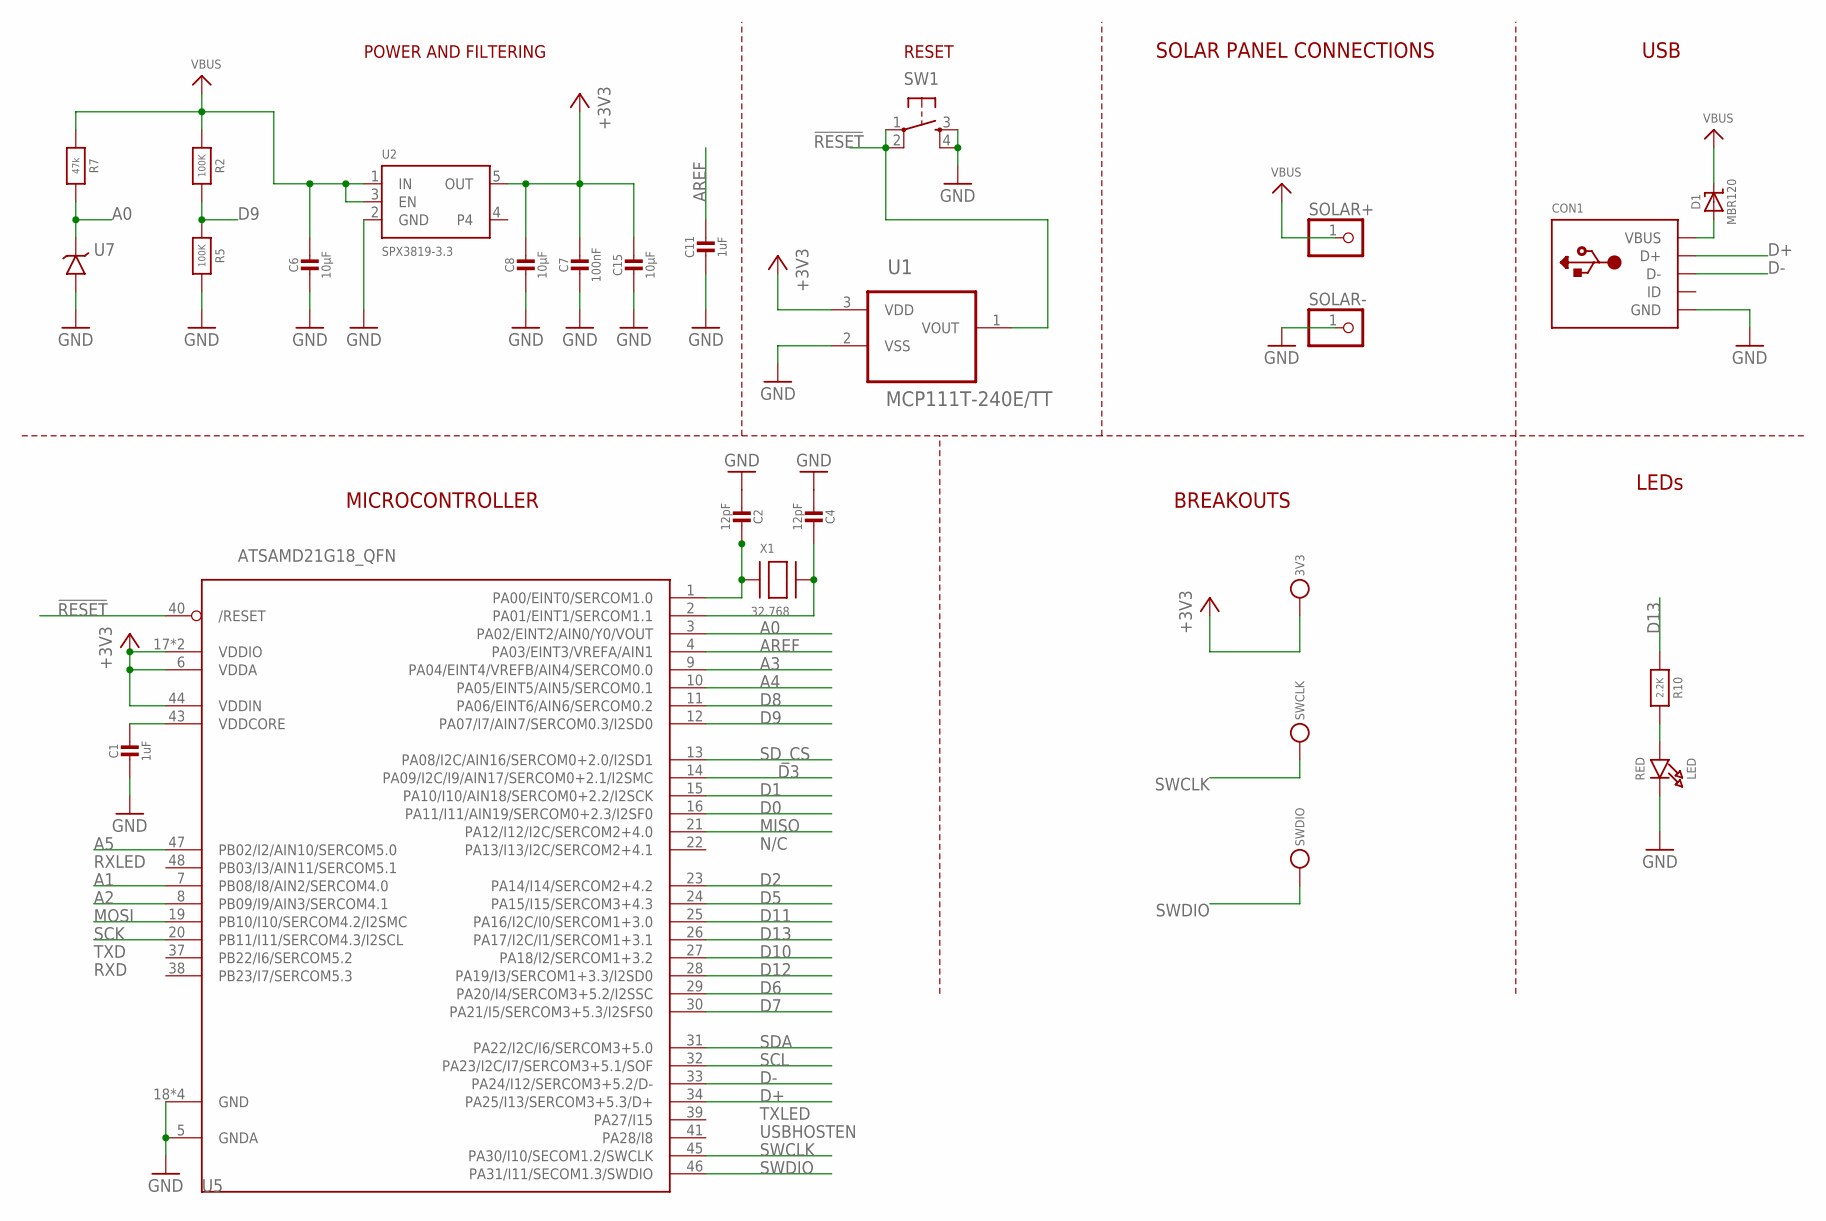
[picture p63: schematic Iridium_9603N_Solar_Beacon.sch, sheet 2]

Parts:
3V3: TESTPOINTROUND1.5MM; TESTPOINT_ROUND_1.5MM
C1, C11: 1uF; 0603-NO
C2, C4: 12pF; 0603-NO
C6, C8, C15: 10µF; 0805-NO
C7: 100nF; 0603-NO
CON1: MICROBUILDER_USBFCI_10103594_CORRECTED; MICROBUILDER_FCI_10103594_CORRECTED
D1: MBR120; SOD-123
LED: RED; CHIPLED_0805_NOOUTLINE
R2, R5: 100K; 0603-NO
R7: 47k; 0603-NO
R10: 2.2K; 0603-NO
SOLAR+: PINHD-1X1; 1X01
SOLAR-: PINHD-1X1; 1X01
SW1: SWITCH_SPST_4_PINRECT; TACTILE_SWITCH_SMD_4.6X2.8MM
SWCLK: TESTPOINTROUND1.5MM; TESTPOINT_ROUND_1.5MM
SWDIO: TESTPOINTROUND1.5MM; TESTPOINT_ROUND_1.5MM
U1: MCP111T-240E/TT; SOT95P237X112-3N; MPN MCP111T-240E/TT
U2: SPX3819-3.3; SOT23-5
U5: ATSAMD21G18_QFN; TQFN48_7MM
U7: LT1634-1,25BMCMS8; MSOP8
X1: 32.768; XTAL3215

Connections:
!RESET: SW1.1, SW1.2, U1.1 (VOUT), U5.40 (/RESET)
+3V3: 3V3.P$1, C7.1, C8.1, C15.1, U1.3 (VDD), U2.5 (OUT), U5.6 (VDDA), U5.17 (VDDIO), U5.36 (VDDIO), U5.44 (VDDIN); also elsewhere on the board
A0: R7.2, U5.3 (PA02/EINT2/AIN0/Y0/VOUT), U7.6 (VOUT)
A1: U5.7 (PB08/I8/AIN2/SERCOM4.0); also elsewhere on the board
A2: U5.8 (PB09/I9/AIN3/SERCOM4.1)
A3: U5.9 (PA04/EINT4/VREFB/AIN4/SERCOM0.0)
A4: U5.10 (PA05/EINT5/AIN5/SERCOM0.1)
A5: U5.47 (PB02/I2/AIN10/SERCOM5.0)
AREF: C11.1, U5.4 (PA03/EINT3/VREFA/AIN1)
D0: U5.16 (PA11/I11/AIN19/SERCOM0+2.3/I2SF0); also elsewhere on the board
D1: U5.15 (PA10/I10/AIN18/SERCOM0+2.2/I2SCK); also elsewhere on the board
D2: U5.23 (PA14/I14/SERCOM2+4.2)
D3: U5.14 (PA09/I2C/I9/AIN17/SERCOM0+2.1/I2SMC)
D5: U5.24 (PA15/I15/SERCOM3+4.3); also elsewhere on the board
D6: U5.29 (PA20/I4/SERCOM3+5.2/I2SSC); also elsewhere on the board
D7: U5.30 (PA21/I5/SERCOM3+5.3/I2SFS0)
D8: U5.11 (PA06/EINT6/AIN6/SERCOM0.2)
D9: R2.2, R5.1, U5.12 (PA07/I7/AIN7/SERCOM0.3/I2SD0)
D10: U5.27 (PA18/I2/SERCOM1+3.2); also elsewhere on the board
D11: U5.25 (PA16/I2C/I0/SERCOM1+3.0); also elsewhere on the board
D12: U5.28 (PA19/I3/SERCOM1+3.3/I2SD0); also elsewhere on the board
D13: R10.1, U5.26 (PA17/I2C/I1/SERCOM1+3.1)
D+: CON1.D+, U5.34 (PA25/I13/SERCOM3+5.3/D+)
D-: CON1.D-, U5.33 (PA24/I12/SERCOM3+5.2/D-)
GND: C1.2, C2.2, C4.2, C6.2, C7.2, C8.2, C11.2, C15.2, CON1.BASE@1 (GND), CON1.BASE@2 (GND), CON1.GND, CON1.SPRT@1 (GND), CON1.SPRT@2 (GND), CON1.SPRT@3 (GND), CON1.SPRT@4 (GND), LED.C, R5.2, SOLAR-.1, SW1.3, SW1.4, U1.2 (VSS), U2.2 (GND), U5.5 (GNDA), U5.18 (GND), U5.35 (GND), U5.42 (GND), U5.THERMAL (GND), U7.4 (GND); also elsewhere on the board
MISO: U5.21 (PA12/I12/I2C/SERCOM2+4.0); also elsewhere on the board
MOSI: U5.19 (PB10/I10/SERCOM4.2/I2SMC)
unnamed: LED.A, R10.2
unnamed: C2.1, U5.1 (PA00/EINT0/SERCOM1.0), X1.P$1
unnamed: C4.1, U5.2 (PA01/EINT1/SERCOM1.1), X1.P$2
unnamed: CON1.VBUS, D1.A
SCK: U5.20 (PB11/I11/SERCOM4.3/I2SCL)
SCL: U5.32 (PA23/I2C/I7/SERCOM3+5.1/SOF); also elsewhere on the board
SDA: U5.31 (PA22/I2C/I6/SERCOM3+5.0)
SD_CS: U5.13 (PA08/I2C/AIN16/SERCOM0+2.0/I2SD1)
SWCLK: SWCLK.P$1, U5.45 (PA30/I10/SECOM1.2/SWCLK)
SWDIO: SWDIO.P$1, U5.46 (PA31/I11/SECOM1.3/SWDIO)
VBUS: C6.1, D1.C, R2.1, R7.1, SOLAR+.1, U2.1 (IN), U2.3 (EN); also elsewhere on the board
VDDCORE1: C1.1, U5.43 (VDDCORE)

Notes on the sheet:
POWER AND FILTERING
RESET
N/C
TXLED
USBHOSTEN
RXLED
TXD
RXD
USB
BREAKOUTS
LEDs
MICROCONTROLLER
SOLAR PANEL CONNECTIONS

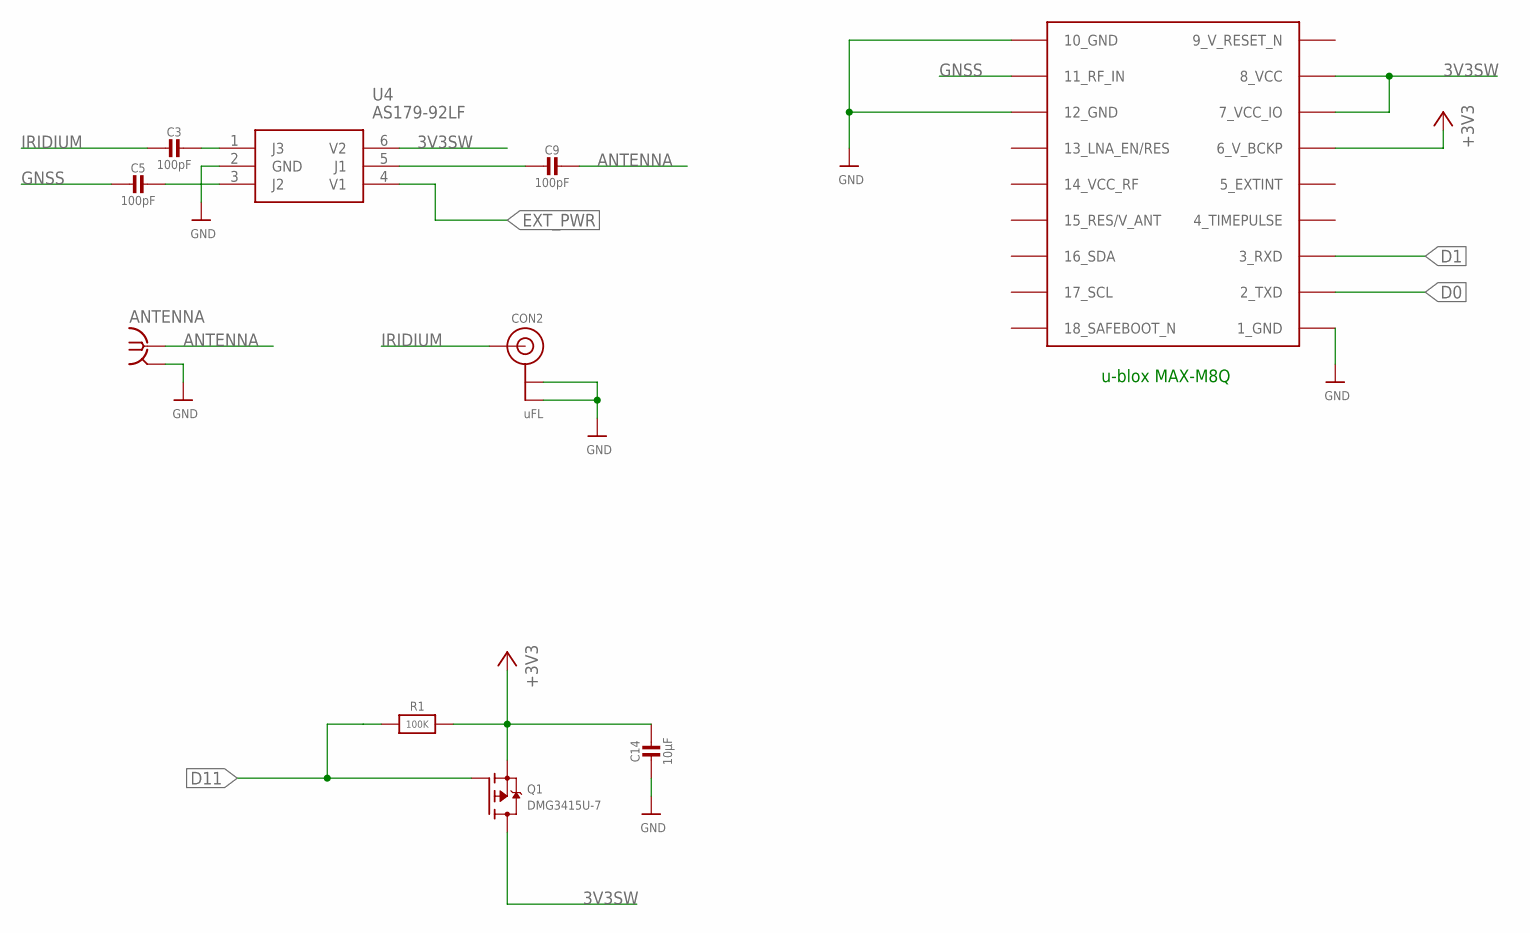
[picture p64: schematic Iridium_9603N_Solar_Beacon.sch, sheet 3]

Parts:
ANTENNA: SMA-142-0711-821/826; J502-ND-142-0711-821/826
C3, C5, C9: 100pF; 0603-NO
C14: 10µF; 0805-NO
CON2: uFL; U.FL
Q1: DMG3415U-7; SOT23-WIDE
R1: 100K; 0603-NO
U4: AS179-92LF; SOT65P220X100-6N
U6: MAX-M8

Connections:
3V3SW: Q1.3 (D), U4.6 (V2), U6.7_VCC_IO, U6.8_VCC
9_V_RESET_N: U6.9_RESET_N (9_V_RESET_N)
+3V3: C14.1, Q1.2 (S), R1.2, U6.6_V_BCKP; also elsewhere on the board
ANTENNA: ANTENNA.1, C9.1
D0: U6.2_TXD; also elsewhere on the board
D1: U6.3_RXD; also elsewhere on the board
D11: Q1.1 (G), R1.1; also elsewhere on the board
EXT_PWR: U4.4 (V1); also elsewhere on the board
GND: ANTENNA.G@1 (2), ANTENNA.G@2 (2), ANTENNA.G@3 (2), ANTENNA.G@4 (2), C14.2, CON2.1 (GND), CON2.2 (GND), U4.2 (GND), U6.1_GND, U6.10_GND, U6.12_GND; also elsewhere on the board
GNSS: C5.2, U6.11_RF_IN
IRIDIUM: C3.2, CON2.3 (SIGNAL)
unnamed: C3.1, U4.1 (J3)
unnamed: C5.1, U4.3 (J2)
unnamed: C9.2, U4.5 (J1)

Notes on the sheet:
u-blox MAX-M8Q

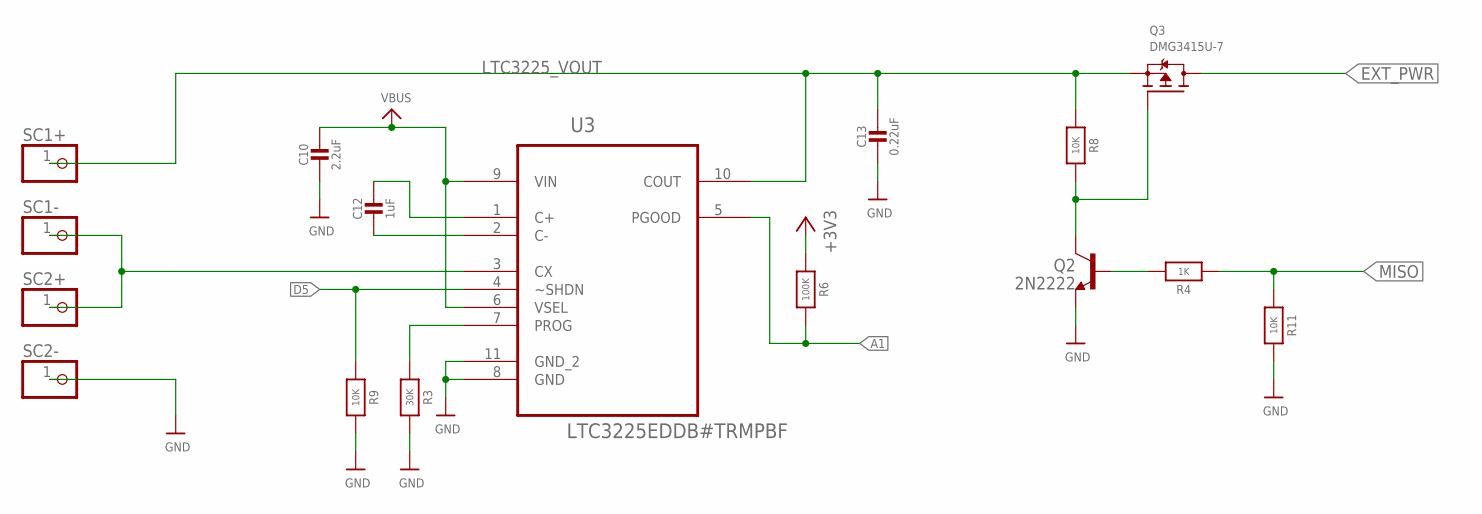
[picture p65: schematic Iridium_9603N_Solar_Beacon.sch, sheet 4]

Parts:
C10: 2.2uF; 0603-NO
C12: 1uF; 0603-NO
C13: 0.22uF; 0603-NO
Q2: 2N2222; SOT23-BEC
Q3: DMG3415U-7; SOT23-WIDE
R3: 30K; 0603-NO
R4: 1K; 0603-NO
R6: 100K; 0603-NO
R8, R9, R11: 10K; 0603-NO
SC1+, SC1-, SC2+, SC2-: PINHD-1X1; 1X01
U3: LTC3225EDDB#TRMPBF; DFN300X200-10L

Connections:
+3V3: R6.1; also elsewhere on the board
A1: R6.2, U3.5 (PGOOD); also elsewhere on the board
D5: R9.1, U3.4 (~SHDN); also elsewhere on the board
EXT_PWR: Q3.3 (D); also elsewhere on the board
GND: C10.2, C13.2, Q2.E, R3.2, R9.2, R11.2, SC2-.1, U3.8 (GND), U3.11 (GND_2); also elsewhere on the board
LTC3225_VOUT: C13.1, Q3.2 (S), R8.1, SC1+.1, U3.10 (COUT)
MISO: R4.1, R11.1; also elsewhere on the board
unnamed: SC1-.1, SC2+.1, U3.3 (CX)
unnamed: C12.2, U3.2 (C-)
unnamed: C12.1, U3.1 (C+)
unnamed: R3.1, U3.7 (PROG)
unnamed: Q2.C, Q3.1 (G), R8.2
unnamed: Q2.B, R4.2
VBUS: C10.1, U3.6 (VSEL), U3.9 (VIN); also elsewhere on the board

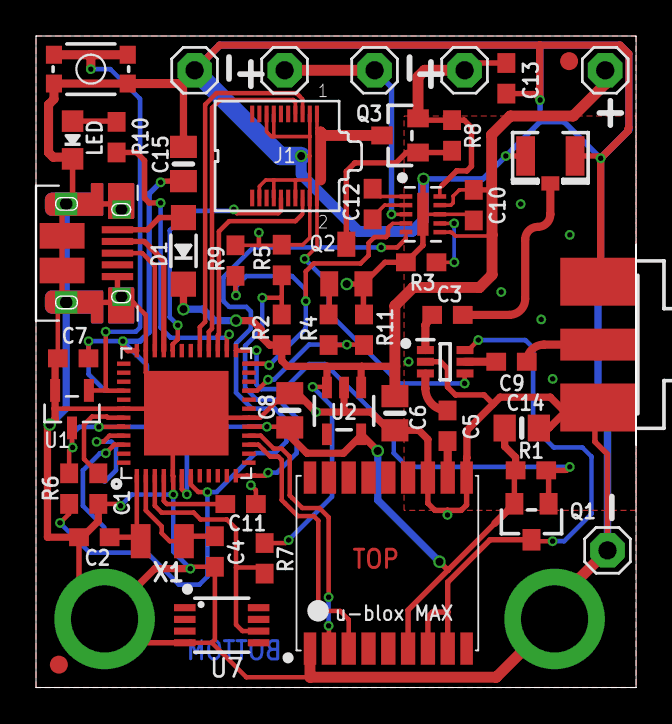
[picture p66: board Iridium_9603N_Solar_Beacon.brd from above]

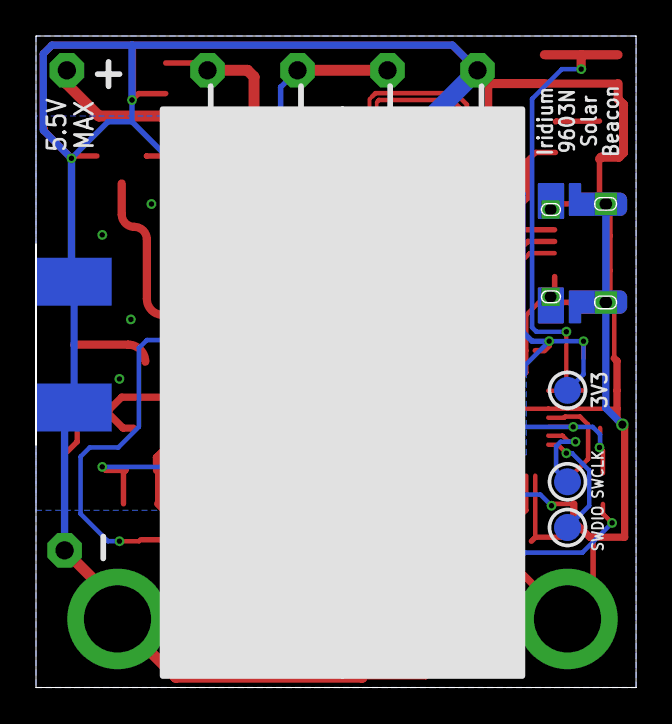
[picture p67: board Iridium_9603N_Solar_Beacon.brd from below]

Board: 2 copper layers, 33.3 x 36.2 mm, 57 parts (3 on the bottom side), 42 nets.

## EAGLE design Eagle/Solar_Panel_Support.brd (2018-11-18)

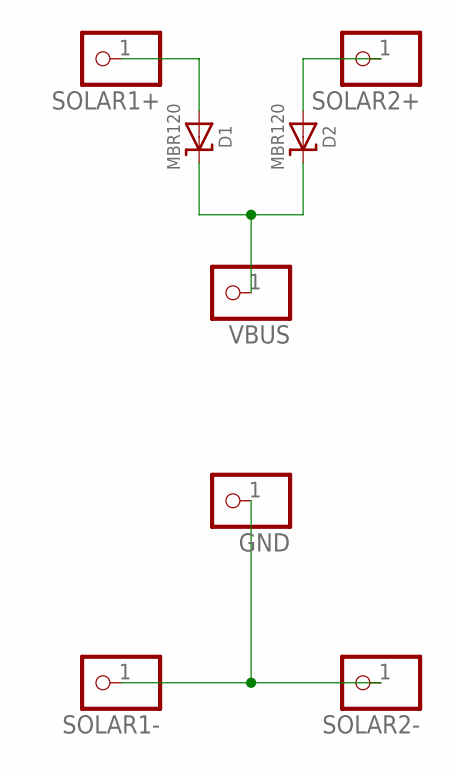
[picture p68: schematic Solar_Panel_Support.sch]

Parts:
D1, D2: MBR120; SOD-123
GND: PINHD-1X1; 1X01
SOLAR1+, SOLAR1-, SOLAR2+, SOLAR2-: PINHD-1X1; 1X01
VBUS: PINHD-1X1; 1X01

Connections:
unnamed: D2.A, SOLAR2+.1
unnamed: D1.C, D2.C, VBUS.1
unnamed: GND.1, SOLAR1-.1, SOLAR2-.1
unnamed: D1.A, SOLAR1+.1

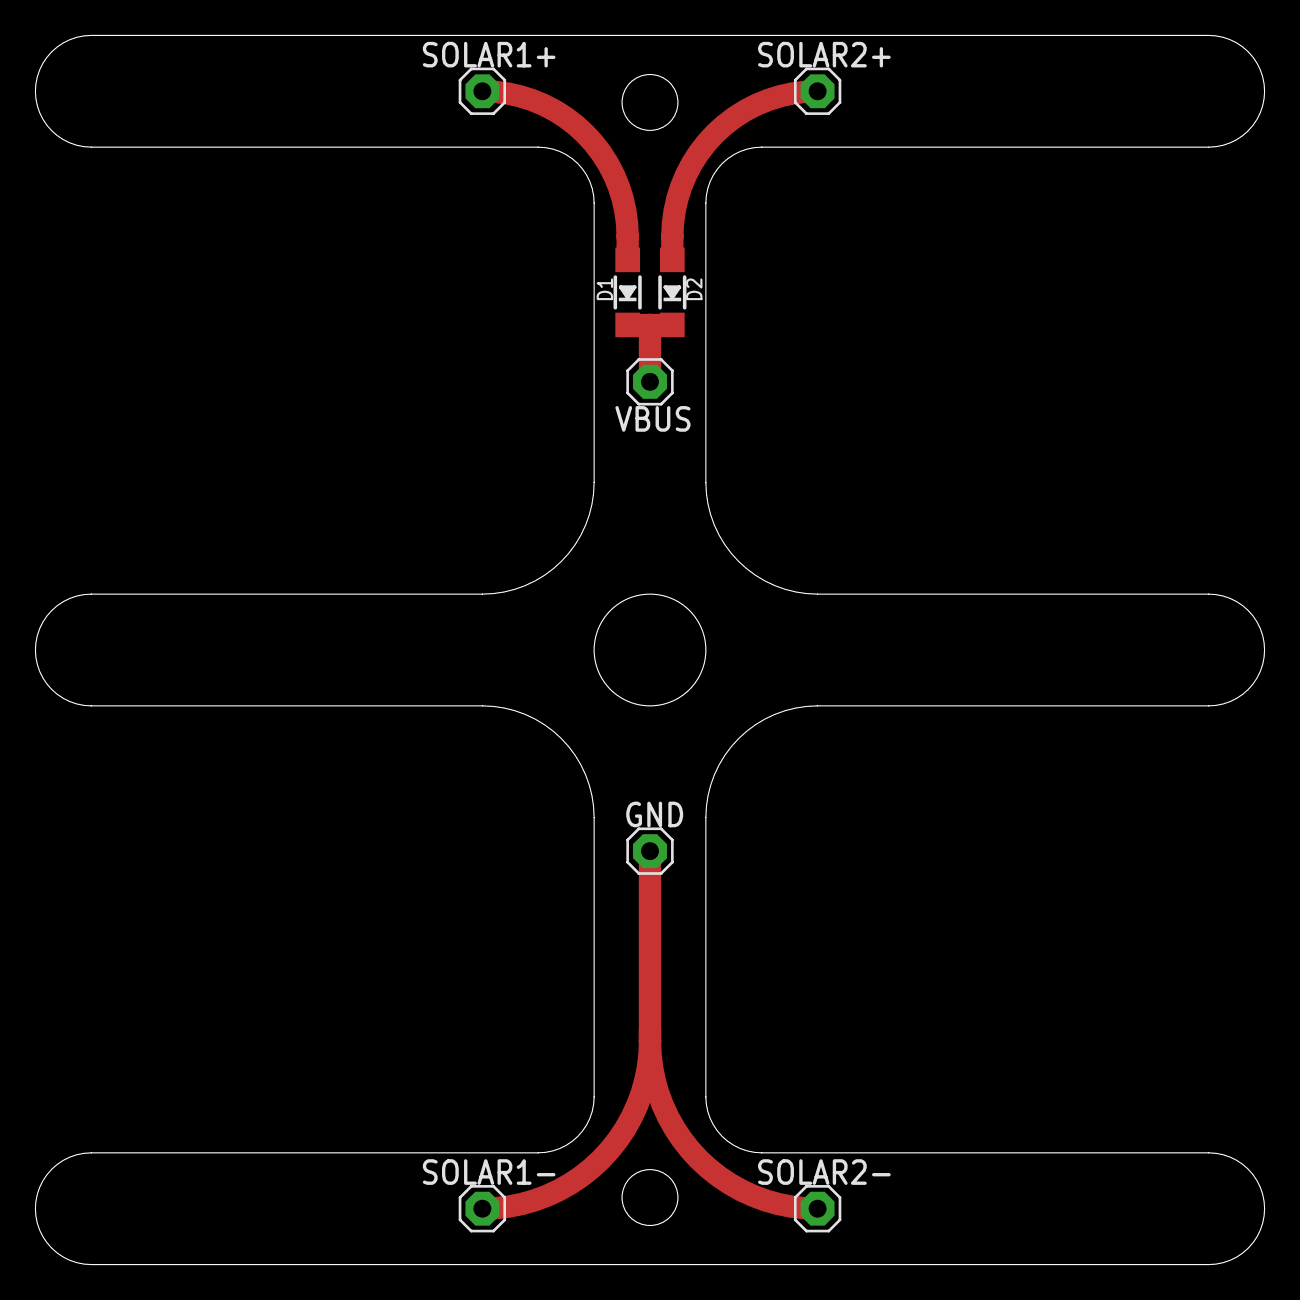
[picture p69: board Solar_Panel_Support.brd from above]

Board: 2 copper layers, 69.8 x 69.8 mm, 8 parts (0 on the bottom side), 4 nets.

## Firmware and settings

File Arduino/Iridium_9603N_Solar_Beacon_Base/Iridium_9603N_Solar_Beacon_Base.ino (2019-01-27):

// ###################################
// # Iridium 9603N Solar Beacon Base #
// ###################################

// Written for the Iridium 9603N Solar Beacon
// This code acts as a 'base station'. When connected to a laptop, allows messages from other Iridium Beacons to be received via RockBLOCK

// Message delivery is via Rock7's RockBLOCK:
// http://www.rock7mobile.com/products-rockblock-9603
// http://www.rock7mobile.com/downloads/RockBLOCK-9603-Developers-Guide.pdf (see last page)

// Assumptions:
// Power will be provided by USB. No battery voltage monitoring is necessary.
// No sleep functionality is required. Base beacon is always on.
// Code will be accessed via the Arduino IDE Serial Monitor - or - matching Python code.

// GNSS / Iridium antenna switching is via a Skyworks AS179-92LF RF Switch
// Switching is performed by applying either EXT_PWR or 3V3SW to the AS179's V1 and V2 pins
// EXT_PWR is the 5.3V power rail for the 9603N (switched via Q2 and Q3, enabled by pulling MISO/D22 high)
// 3V3SW is the 3.3V power rail for the MAX-M8Q (switched via Q1, enabled by pulling D11 low)
// Take great care to make sure EXT_PWR and 3V3SW are not enabled at the same time!
// BADS THINGS WILL PROBABLY HAPPEN IF YOU DO ENABLE BOTH SIMULTANEOUSLY!

// With grateful thanks to Mikal Hart:
// Based on Mikal's IridiumSBD Beacon example: https://github.com/mikalhart/IridiumSBD
// Requires Mikal's TinyGPS library: https://github.com/mikalhart/TinyGPS
// and PString: http://arduiniana.org/libraries/pstring/

// With grateful thanks to:
// Adafruit: https://learn.adafruit.com/using-atsamd21-sercom-to-add-more-spi-i2c-serial-ports/creating-a-new-serial
// MartinL: https://forum.arduino.cc/index.php?topic=341054.msg2443086#msg2443086

// The Iridium_9603_Beacon PCB is based extensively on the Adafruit Feather M0 (Adalogger)
// https://www.adafruit.com/products/2796

// GPS data provided by u-blox MAX-M8Q
// https://www.u-blox.com/en/product/max-m8-series

// Iridium 9603N is interfaced to M0 using Serial2
// D6 (Port A Pin 20) = Enable (Sleep) : Connect to 9603 ON/OFF Pin 5
// D10 (Port A Pin 18) = Serial2 TX : Connect to 9603 Pin 6
// D12 (Port A Pin 19) = Serial2 RX : Connect to 9603 Pin 7
// D21 (Port A Pin 23) = Ring Indicator: Connected to 9603 Pin 12

// Power to the 9603N is switched by a P-channel MOSFET
// The MOSFET gate is pulled high by a 10K resistor. The gate is pulled low by a 2N2222 NPN transistor
// Power is enabled by pulling the base of the transistor high
// The transistor base is connected to MISO / D22

// Iridium 9603 is powered from Linear Technology LTC3225 SuperCapacitor Charger
// (fitted with 2 x 10F 2.7V caps e.g. Bussmann HV1030-2R7106-R)
// to provide the 1.3A peak current when the 9603 is transmitting.
// Charging 10F capacitors to 5.3V at 60mA could take ~7 minutes!
// (~6.5 mins to PGOOD, ~7 mins to full charge)
// 5.3V is OK as the 9603N has an extended supply voltage range of +5 V +/- 0.5 V
// http://www.linear.com/product/LTC3225
// D5 (Port A Pin 15) = LTC3225 ~Shutdown
// A1 / D15 (Port B Pin 8) = LTC3225 PGOOD

// MAX-M8Q GNSS is interfaced to M0 using Serial1
// D1 (Port A Pin 10) = Serial1 TX : Connect to GPS RX
// D0 (Port A Pin 11) = Serial1 RX : Connect to GPS TX
// D11 (Port A Pin 16) = GPS ENable : Connect to GPS EN(ABLE)

// D13 (Port A Pin 17) = WB2812B NeoPixel + single Red LED
// D9 (Port A Pin 7) = AIN 7 : Bus Voltage / 2
// D14 (Port A Pin 2) = AIN 0 : 1.25V precision voltage reference

// As the supply voltage drops, reported VBUS on A7 drops to ~3.4V and then flatlines
// as the 3.3V rail starts to collapse. The 1.25V reference on A0 allows lower voltages to be measured
// as the signal on A0 will appear to _rise_ as the 3.3V rail collapses.

// Red LED on D13 shows when the SAMD is in bootloader mode (LED will fade up/down)

#include <IridiumSBD.h> // Requires V2: https://github.com/mikalhart/IridiumSBD
#include <TinyGPS.h> // NMEA parsing: http://arduiniana.org
#include <PString.h> // String buffer formatting: http://arduiniana.org

// Serial2 pin and pad definitions (in Arduino files Variant.h & Variant.cpp)
#define PIN_SERIAL2_RX       (34ul)               // Pin description number for PIO_SERCOM on D12
#define PIN_SERIAL2_TX       (36ul)               // Pin description number for PIO_SERCOM on D10
#define PAD_SERIAL2_TX       (UART_TX_PAD_2)      // SERCOM pad 2 (SC1PAD2)
#define PAD_SERIAL2_RX       (SERCOM_RX_PAD_3)    // SERCOM pad 3 (SC1PAD3)
// Instantiate the Serial2 class
Uart Serial2(&sercom1, PIN_SERIAL2_RX, PIN_SERIAL2_TX, PAD_SERIAL2_RX, PAD_SERIAL2_TX);
HardwareSerial &ssIridium(Serial2);

#define ssGPS Serial1 // Use M0 Serial1 to interface to the MAX-M8Q

// Leave the "#define GALILEO" uncommented to use: GPS + Galileo + GLONASS + SBAS
// Comment the "#define GALILEO" out to use the default u-blox M8 GNSS: GPS + SBAS + QZSS + GLONASS
#define GALILEO

// Set Nav Mode to Portable
static const uint8_t setNavPortable[] = {
  0xB5, 0x62, 0x06, 0x24, 0x24, 0x00, 0x01, 0x00, 0x00, 0x03, 0x00, 0x00, 0x00, 0x00, 0x10, 0x27, 0x00, 0x00, 
  0x05, 0x00, 0xFA, 0x00, 0xFA, 0x00, 0x64, 0x00, 0x2C, 0x01, 0x00, 0x00, 0x00, 0x00, 0x00, 0x00, 0x00, 0x00, 
  0x00, 0x00, 0x00, 0x00, 0x00, 0x00 };

// Set Nav Mode to Pedestrian
static const uint8_t setNavPedestrian[] = {
  0xB5, 0x62, 0x06, 0x24, 0x24, 0x00, 0x01, 0x00, 0x03, 0x03, 0x00, 0x00, 0x00, 0x00, 0x10, 0x27, 0x00, 0x00, 
  0x05, 0x00, 0xFA, 0x00, 0xFA, 0x00, 0x64, 0x00, 0x2C, 0x01, 0x00, 0x00, 0x00, 0x00, 0x00, 0x00, 0x00, 0x00, 
  0x00, 0x00, 0x00, 0x00, 0x00, 0x00 };

// Set Nav Mode to Automotive
static const uint8_t setNavAutomotive[] = {
  0xB5, 0x62, 0x06, 0x24, 0x24, 0x00, 0x01, 0x00, 0x04, 0x03, 0x00, 0x00, 0x00, 0x00, 0x10, 0x27, 0x00, 0x00, 
  0x05, 0x00, 0xFA, 0x00, 0xFA, 0x00, 0x64, 0x00, 0x2C, 0x01, 0x00, 0x00, 0x00, 0x00, 0x00, 0x00, 0x00, 0x00, 
  0x00, 0x00, 0x00, 0x00, 0x00, 0x00 };

// Set Nav Mode to Sea
static const uint8_t setNavSea[] = {
  0xB5, 0x62, 0x06, 0x24, 0x24, 0x00, 0x01, 0x00, 0x05, 0x03, 0x00, 0x00, 0x00, 0x00, 0x10, 0x27, 0x00, 0x00, 
  0x05, 0x00, 0xFA, 0x00, 0xFA, 0x00, 0x64, 0x00, 0x2C, 0x01, 0x00, 0x00, 0x00, 0x00, 0x00, 0x00, 0x00, 0x00, 
  0x00, 0x00, 0x00, 0x00, 0x00, 0x00 };

// Set Nav Mode to Airborne <1G
static const uint8_t setNavAir[] = {
  0xB5, 0x62, 0x06, 0x24, 0x24, 0x00, 0x01, 0x00, 0x06, 0x03, 0x00, 0x00, 0x00, 0x00, 0x10, 0x27, 0x00, 0x00, 
  0x05, 0x00, 0xFA, 0x00, 0xFA, 0x00, 0x64, 0x00, 0x2C, 0x01, 0x00, 0x00, 0x00, 0x00, 0x00, 0x00, 0x00, 0x00, 
  0x00, 0x00, 0x00, 0x00, 0x00, 0x00 };

static const int len_setNav = 42;

// Set NMEA Config
// Set trackFilt to 1 to ensure course (COG) is always output
// Set Main Talker ID to 'GP' to avoid having to modify TinyGPS
static const uint8_t setNMEA[] = {
  0xb5, 0x62, 0x06, 0x17, 0x14, 0x00, 0x20, 0x40, 0x00, 0x02, 0x00, 0x00, 0x00, 0x00, 0x00, 0x01, 0x01, 0x01,
  0x00, 0x00, 0x00, 0x00, 0x00, 0x00, 0x00, 0x00 };
static const int len_setNMEA = 26;

// Set GNSS Config to GPS + Galileo + GLONASS + SBAS (Causes the M8 to restart!)
static const uint8_t setGNSS[] = {
  0xb5, 0x62, 0x06, 0x3e, 0x3c, 0x00,
  0x00, 0x20, 0x20, 0x07,
  0x00, 0x08, 0x10, 0x00, 0x01, 0x00, 0x01, 0x01,
  0x01, 0x01, 0x03, 0x00, 0x01, 0x00, 0x01, 0x01,
  0x02, 0x04, 0x08, 0x00, 0x01, 0x00, 0x01, 0x01,
  0x03, 0x08, 0x10, 0x00, 0x00, 0x00, 0x01, 0x01,
  0x04, 0x00, 0x08, 0x00, 0x00, 0x00, 0x01, 0x03,
  0x05, 0x00, 0x03, 0x00, 0x00, 0x00, 0x01, 0x05,
  0x06, 0x08, 0x0e, 0x00, 0x01, 0x00, 0x01, 0x01 };
static const int len_setGNSS = 66;

// Clear Stored Configuration
// Clears msgConf, navConf, rxmConf
static const uint8_t clearConf[] = {
  0xb5, 0x62, 0x06, 0x09, 0x0C, 0x00,
  0x1A, 0x00, 0x00, 0x00, 0x00, 0x00, 0x00, 0x00, 0x00, 0x00, 0x00, 0x00 };
// Save Configuration
// Saves msgConf, navConf, rxmConf
static const uint8_t saveConf[] = {
  0xb5, 0x62, 0x06, 0x09, 0x0C, 0x00,
  0x00, 0x00, 0x00, 0x00, 0x1A, 0x00, 0x00, 0x00, 0x00, 0x00, 0x00, 0x00 };
// Load Configuration
// Loads msgConf, navConf, rxmConf
static const uint8_t loadConf[] = {
  0xb5, 0x62, 0x06, 0x09, 0x0C, 0x00,
  0x00, 0x00, 0x00, 0x00, 0x00, 0x00, 0x00, 0x00, 0x1A, 0x00, 0x00, 0x00 };
static const int len_Conf = 18;

static const int LTC3225shutdown = 5; // LTC3225 ~Shutdown on pin D5
static const int LTC3225PGOOD = 15; // LTC3225 PGOOD on pin A1 / D15
static const int Enable_9603N = 22; // 9603N Enable (enables EXT_PWR via P-MOSFET)
static const int RingIndicator = 21; // Iridium Ring Indicator connected to D21
static const int IridiumSleepPin = 6; // Iridium Sleep connected to D6
IridiumSBD isbd(ssIridium, IridiumSleepPin); // This should disable the 9603
TinyGPS tinygps;
static const int ledPin = 13; // WB2812B + Red LED on pin D13
long iterationCounter = 0; // Increment each time a transmission is attempted

static const int GPS_EN = 11; // GPS Enable on pin D11
#define GPS_ON LOW
#define GPS_OFF HIGH
#define VAP A7 // Bus voltage analog pin (bus voltage divided by 2)
#define VREF A0 // 1.25V precision voltage reference
#define VBUS_NORM 3.3 // Normal bus voltage for battery voltage calculations
#define VREF_NORM 1.25 // Normal reference voltage for battery voltage calculations
#define VBAT_LOW 3.05 // Minimum voltage for LTC3225

// Loop Steps
#define init          0
#define start_LTC3225 1
#define menu_choice   2
#define read_GPS      3
#define read_pressure 4
#define start_9603    5
#define flush_queue   6
#define read_battery  7
#define power_down    8
#define send_message  9

// Variables used by Loop
int year;
byte month, day, hour, minute, second, hundredths;
unsigned long dateFix, locationFix;
float latitude, longitude;
long altitude;
float speed;
short satellites;
long course;
long hdop;
bool fixFound = false;
bool charsSeen = false;
int loop_step = init;
float vbat = 5.0;
float vref = VREF_NORM;
float vrail = VBUS_NORM;
int PGOOD;
unsigned long tnow;

// IridiumSBD Callbacks
bool ISBDCallback()
{
  // 'Flash' the LED
  if ((millis() / 1000) % 2 == 1) {
    digitalWrite(ledPin, HIGH);
  }
  else {
    digitalWrite(ledPin, LOW);
  }
  return true;
}
// V2 console and diagnostic callbacks (replacing attachConsole and attachDiags)
// Comment the next two lines to disable diagnostic messages
//void ISBDConsoleCallback(IridiumSBD *device, char c) { Serial.write(c); }
//void ISBDDiagsCallback(IridiumSBD *device, char c) { Serial.write(c); }

// Interrupt handler for SERCOM1 (essential for Serial2 comms)
void SERCOM1_Handler()
{
  Serial2.IrqHandler();
}

// Read 'battery' voltage
void get_vbat() {
  // Measure the reference voltage and calculate the rail voltage
  vref = analogRead(VREF) * (VBUS_NORM / 1023.0);
  vrail = VREF_NORM * VBUS_NORM / vref;

  vbat = analogRead(VAP) * (2.0 * vrail / 1023.0); // Read 'battery' voltage from resistor divider, correcting for vrail
}

// Send message in u-blox UBX format
// Calculates and appends the two checksum bytes
// Doesn't add the 0xb5 and 0x62 sync chars (these need to be included at the start of the message)
void sendUBX(const uint8_t *message, const int len) {
  int csum1 = 0; // Checksum bytes
  int csum2 = 0;
  for (int i=0; i<len; i++) { // For each byte in the message
    ssGPS.write(message[i]); // Write the byte
    if (i >= 2) { // Don't include the sync chars in the checksum
      csum1 = csum1 + message[i]; // Update the checksum bytes
      csum2 = csum2 + csum1;
    }
  }
  csum1 = csum1 & 0xff; // Limit checksums to 8-bits
  csum2 = csum2 & 0xff;
  ssGPS.write((uint8_t)csum1); // Send the checksum bytes
  ssGPS.write((uint8_t)csum2);
}

// Flash the LED quickly
void flash_LED(unsigned long duration) {
  for (tnow = millis(); millis() - tnow < duration * 1000UL;)
  {
    if ((millis() / 100) % 2 == 1) {
      digitalWrite(ledPin, HIGH);
    }
    else {
      digitalWrite(ledPin, LOW);
    }
  }
}

void setup()
{
  pinMode(LTC3225shutdown, OUTPUT); // LTC3225 supercapacitor charger shutdown pin
  digitalWrite(LTC3225shutdown, HIGH); // Enable the LTC3225 supercapacitor charger
  pinMode(LTC3225PGOOD, INPUT); // Define an input for the LTC3225 Power Good signal
  
  pinMode(Enable_9603N, OUTPUT); // 9603N enable via P-FET and NPN transistor
  digitalWrite(Enable_9603N, LOW); // Disable the 9603N
  
  pinMode(GPS_EN, OUTPUT); // GPS enable
  digitalWrite(GPS_EN, GPS_ON); // Enable the GPS
  
  pinMode(IridiumSleepPin, OUTPUT); // The call to IridiumSBD should have done this - but just in case
  digitalWrite(IridiumSleepPin, LOW); // Disable the Iridium 9603
  pinMode(RingIndicator, INPUT_PULLUP); // Define an input for the Iridium 9603 Ring Indicator signal

  pinMode(ledPin, OUTPUT); // LED
  digitalWrite(ledPin, LOW); // Disable the LED
  
  loop_step = init; // Make sure loop_step is set to init
}

void loop()
{
  unsigned long loopStartTime = millis();
  int choice;
  int err;

  switch(loop_step) {

    case init:
      {
      // Start the serial console
      Serial.begin(115200);
      //delay(5000); // Wait 5 secs - allow time for user to open serial monitor
    
      // Send welcome message
      Serial.println("Iridium 9603N Solar Beacon Base:");
      
      // Setup the IridiumSBD
      // (attachConsole and attachDiags methods have been replaced with ISBDConsoleCallback and ISBDDiagsCallback)
      isbd.setPowerProfile(IridiumSBD::USB_POWER_PROFILE); // Change power profile to "low current"
      isbd.useMSSTMWorkaround(false); // Redundant?
      isbd.adjustSendReceiveTimeout(60); // Default is 300 seconds

      // Start the GPS serial port
      ssGPS.begin(9600);

      delay(1000); // Allow time for the port to open

      // Configure GPS
      Serial.println("Configuring GNSS");

      // Initialise the M8 by clearing the stored configuration and then loading it
      sendUBX(clearConf, len_Conf); // Clear stored configuration
      delay(100);
      sendUBX(loadConf, len_Conf); // Load configuration
      delay(2100);

      // Disable all messages except GGA and RMC
      ssGPS.println("$PUBX,40,GLL,0,0,0,0*5C"); // Disable GLL
      delay(1100);
      ssGPS.println("$PUBX,40,ZDA,0,0,0,0*44"); // Disable ZDA
      delay(1100);
      ssGPS.println("$PUBX,40,VTG,0,0,0,0*5E"); // Disable VTG
      delay(1100);
      ssGPS.println("$PUBX,40,GSV,0,0,0,0*59"); // Disable GSV
      delay(1100);
      ssGPS.println("$PUBX,40,GSA,0,0,0,0*4E"); // Disable GSA
      delay(1100);
      
      sendUBX(setNavPortable, len_setNav); // Set Portable Navigation Mode
      //sendUBX(setNavPedestrian, len_setNav); // Set Pedestrian Navigation Mode
      //sendUBX(setNavAutomotive, len_setNav); // Set Automotive Navigation Mode
      //sendUBX(setNavSea, len_setNav); // Set Sea Navigation Mode
      //sendUBX(setNavAir, len_setNav); // Set Airborne <1G Navigation Mode
      delay(1100);

      sendUBX(setNMEA, len_setNMEA); // Set NMEA: to always output COG; and set main talker to GP (instead of GN)
      delay(1100);
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

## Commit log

2018-11-18 Major update for new PCB
    [Iridium_9603N_Solar_Beacon.brd, Iridium_9603N_Solar_Beacon.sch, Solar_Panel_Support.brd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]
2018-12-02 Updated the PCB
    Updated the PCB to improve the ground paths around the SAMD; added extra decoupling capacitors. Minor updates to the Arduino code.
    [Iridium_9603N_Solar_Beacon.brd, Iridium_9603N_Solar_Beacon.sch]
2018-12-03 Connected the Ring Indicator
    Connected the 9603N Ring Indicator to D21 just in case the solar beacon is used as a very compact Beacon Base (powered by USB).
    [Iridium_9603N_Solar_Beacon.brd, Iridium_9603N_Solar_Beacon.sch]
2019-01-17 Corrected the zero width polygons
    Corrected the zero width polygons in the micro USB connector that would have caused problems for OSH Park. Thanks go to Paul Loewen @ usask.ca
    [Iridium_9603N_Solar_Beacon.brd, Iridium_9603N_Solar_Beacon.sch]
2019-01-26 Added LEARN.md, ASSEMBLY.md and extra images
    [Solar_Beacon_Cover.scad, Solar_Beacon_Cover.stl, Solar_Beacon_Lid.scad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]
2019-01-27 Added the Base code and updated the cover
    [Solar_Beacon_Cover.scad, Solar_Beacon_Cover.stl, Solar_Beacon_Lid.scad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]
2019-03-02 Added assembly details for the solar panel support.
2019-03-10 Added the antenna spacer
    [Solar_Beacon_Antenna_Spacer.scad, Solar_Beacon_Antenna_Spacer.stl]
2019-03-17 Improved the battery voltage sampling
    Improved the battery voltage sampling and PGOOD monitoring after testing the beacon on full solar power.
2019-03-18 Added LED flash info

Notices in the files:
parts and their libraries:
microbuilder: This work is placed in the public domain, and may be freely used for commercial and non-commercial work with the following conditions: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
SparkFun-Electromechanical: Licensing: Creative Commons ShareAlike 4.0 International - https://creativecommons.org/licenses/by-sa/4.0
